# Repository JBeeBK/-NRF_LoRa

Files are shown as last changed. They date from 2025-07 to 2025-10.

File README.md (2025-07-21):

# NRF_LoRa

PCB design for a Nordic nRF52840 (QFN48) with SX1262 LoRa module.  
Designed as a low-power mesh node for experimentation and LoRaWan or Meshtastic development.

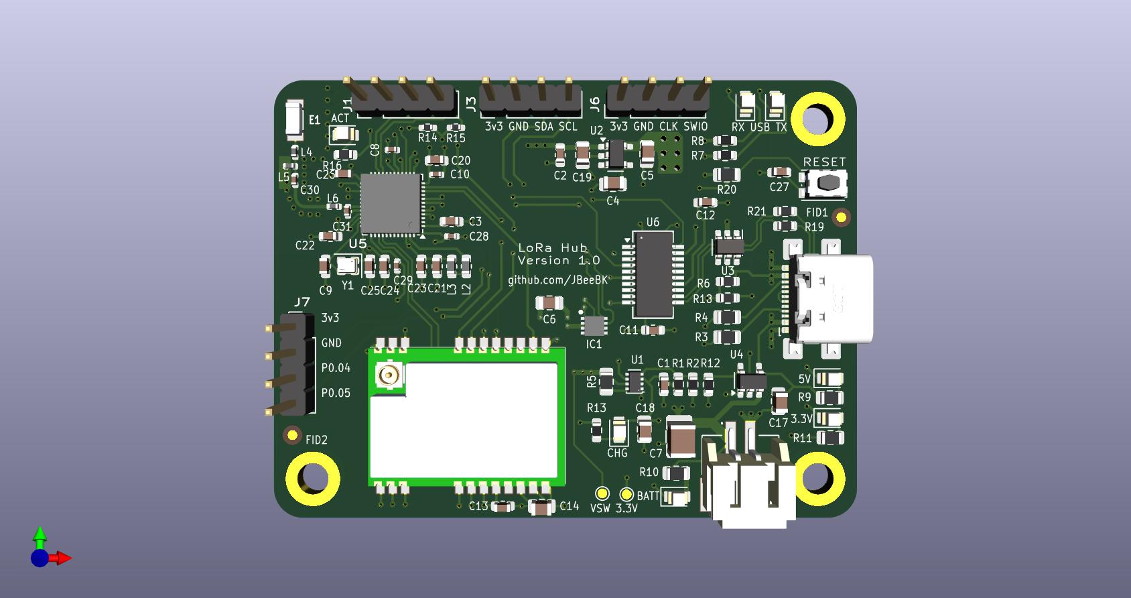
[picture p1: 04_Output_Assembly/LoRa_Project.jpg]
Board Top


### Features
- nRF52840 SoC (BLE, Cortex-M4F)
- SX1262 LoRa (868 MHz) with SMA antenna
- USB-C input with TPS2116 power multiplexer
- MCP73831 LiPo charger and MAX17048 fuel gauge
- 2 x I²C headers for OLED and maybe card keyboard
- FT231XS USB-UART bridge for programming
- Compact 4-layer PCB (60 x 45 mm)
- Additional Header for 2GPIO

### Repository Structure
- `Hardware/` – KiCad source files (schematic, PCB, symbols, footprints)
- `Documents/` – Excel for pinout and pins used, net labels, etc.
- `Output_Pcb/` – Gerbers, fabrication layer PDFs
- `Output_Assembly/` – BOM, pick-and-place, schematic PDFs
- `Firmware/` – C++ file

This repo documents the hardware design; firmware will be added once the board is fabricated.

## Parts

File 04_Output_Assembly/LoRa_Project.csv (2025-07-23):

Id | Designator | Footprint | Quantity | Designation | Supplier and ref
1 | C29,C10,C8,C28,C26 | C_0402_1005Metric | 5 | 100nF
2 | J3,J7,J6,J1 | PinHeader_1x04_P2.54mm_Vertical | 4 | Conn_01x04_Pin
3 | U4 | SOT-23-5 | 1 | MCP73831-2-OT
4 | D7 | LED_0805 | 1 | LED Green
5 | TP5 | TestPoint_Pad_D1.0mm | 1 | 3V3
6 | C12 | C_0603_1608Metric | 1 | 100nF
7 | C27,C11,C13,C3 | C_0603_1608Metric | 4 | 100nF
8 | C5,C14,C19 | C_0805_2012Metric | 3 | 1uF
9 | D6 | LED_0805 | 1 | LED Orange
10 | R15,R14 | R_0402_1005Metric_Pad0.72x0.64mm_HandSolder | 2 | 4k7
11 | TP4 | TestPoint_Pad_D1.0mm | 1 | V_SW
12 | D2 | LED_0805 | 1 | LED Blue
13 | U1 | SOT-583-8 | 1 | TPS2116DRLR
14 | C6,C18,C17 | C_0805_2012Metric | 3 | 100nF
15 | C21,C20 | C_0603_1608Metric | 2 | 1uF
16 | R10,R9 | R_0805_2012Metric | 2 | 1K5_0805
17 | R5,R20 | R_0805_2012Metric | 2 | 10K
18 | R13 | R_0603_1608Metric | 1 | 1K
19 | Y1 | Crystal_SMD_2016-4Pin_2.0x1.6mm | 1 | Crystal
20 | C1,C2 | C_0603_1608Metric | 2 | 10uF
21 | R2,R1 | R_0603_1608Metric | 2 | 100K
22 | U3 | SOT-23-6 | 1 | USBLC6-2SC6
23 | IC2 | E22-900M22S | 1 | E22-900M22S
24 | R16 | R_0603_1608Metric | 1 | 1K_0603
25 | L6 | L_0402_1005Metric | 1 | 4.7nH
26 | R11 | R_0805_2012Metric | 1 | 1K_0805
27 | U2 | SOT-23-5 | 1 | MIC5219-3.3YM5
28 | U6 | SSOP-20_3.9x8.7mm_P0.635mm | 1 | FT231XS
29 | D3 | LED_0805 | 1 | USB PWR
30 | R12 | R_0603_1608Metric | 1 | 10K0_0603
31 | IC1 | SON50P200X200X80-9N-D | 1 | MAX17048G+T10
32 | U5 | QFN-48-1EP_6x6mm_P0.4mm_EP4.6x4.6mm_ThermalVias | 1 | nRF52840-QFAA
33 | J2 | USB_C_Receptacle_GCT_USB4110 | 1 | USB_C_Receptacle_USB2.0_16P
34 | R8,R7 | R_0603_1608Metric | 2 | 270R_0603
35 | R18 | R_0603_1608Metric | 1 | 10K
36 | L5 | L_0402_1005Metric | 1 | 2.7nH
37 | C24 | C_0603_1608Metric | 1 | 100pF
38 | C31 | C_0402_1005Metric | 1 | 1pF
39 | R3,R4 | R_0805_2012Metric | 2 | 5K1_0805
40 | L3 | L_0603_1608Metric | 1 | 15uH
41 | C25,C9 | C_0603_1608Metric | 2 | 8pF
42 | C23 | C_0603_1608Metric | 1 | C_NP
43 | L2 | L_0603_1608Metric | 1 | 10uH
44 | D5 | LED_0805 | 1 | VREG
45 | L4 | L_0402_1005Metric | 1 | 3.3nH
46 | C22 | C_0603_1608Metric | 1 | 47nF
47 | C7 | C_1210_3225Metric | 1 | 10uF
48 | RST1 | SW_Push_1P1T_NO_CK_KMR2 | 1 | ~
49 | R19,R21 | R_0603_1608Metric | 2 | 27
50 | D4 | LED_0805 | 1 | BATT PWR
51 | C4 | C_0805_2012Metric | 1 | 470pF
52 | C30 | C_0402_1005Metric | 1 | 1.2pF
53 | J4 | JST_S2B-PH-SM4-TB_LF__SN_ | 1 | Header_01x02_2.0mm JST PH
54 | E1 | XDCR_2450AT18B100E | 1 | 2450AT18B100E
55 | D1 | LED_0805 | 1 | LED Yellow
56 | R6 | R_0603_1608Metric | 1 | 4k7

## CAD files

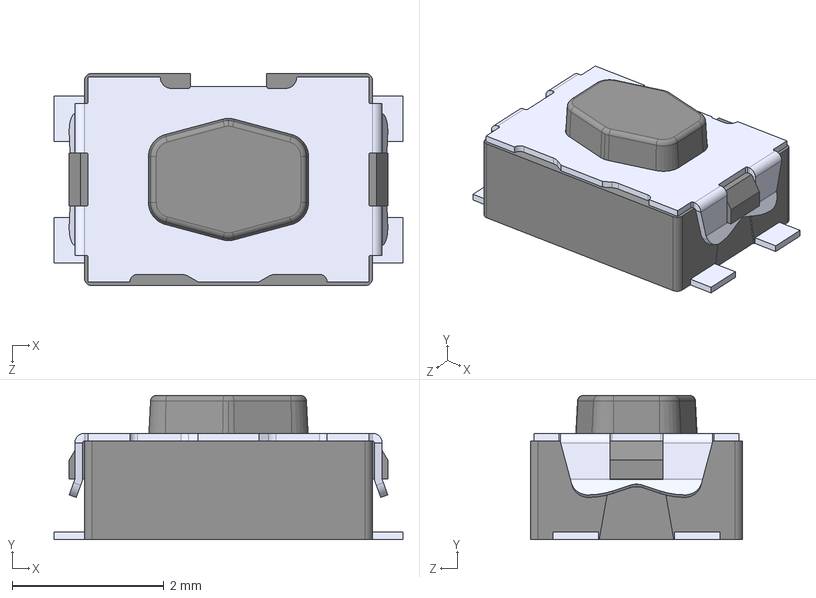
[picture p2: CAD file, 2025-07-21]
00_Hardware/Project_Footprints/KMR211NGLFS.STEP
4.60 x 1.90 x 2.80 mm

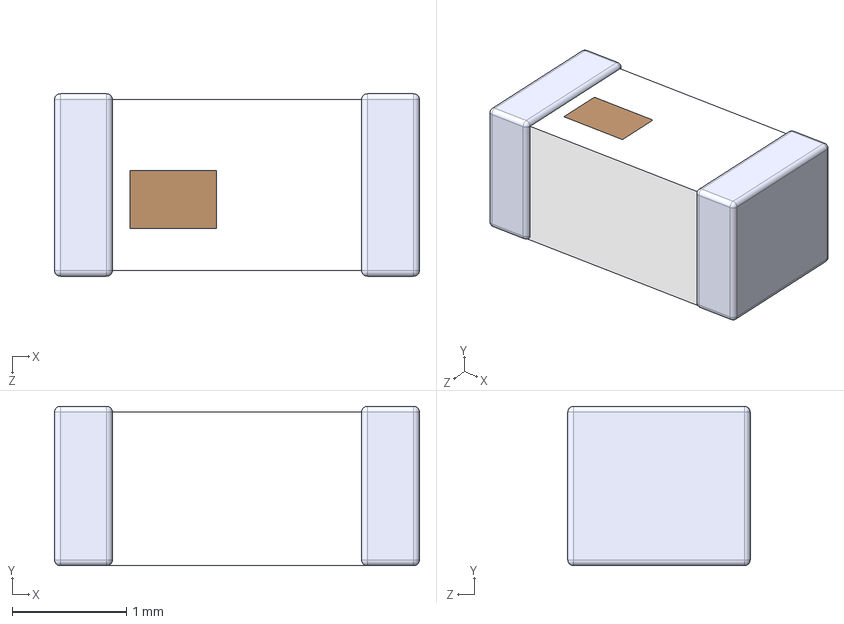
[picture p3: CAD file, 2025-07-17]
00_Hardware/Project_Footprints/2450AT18B100E.step
3.20 x 1.40 x 1.60 mm

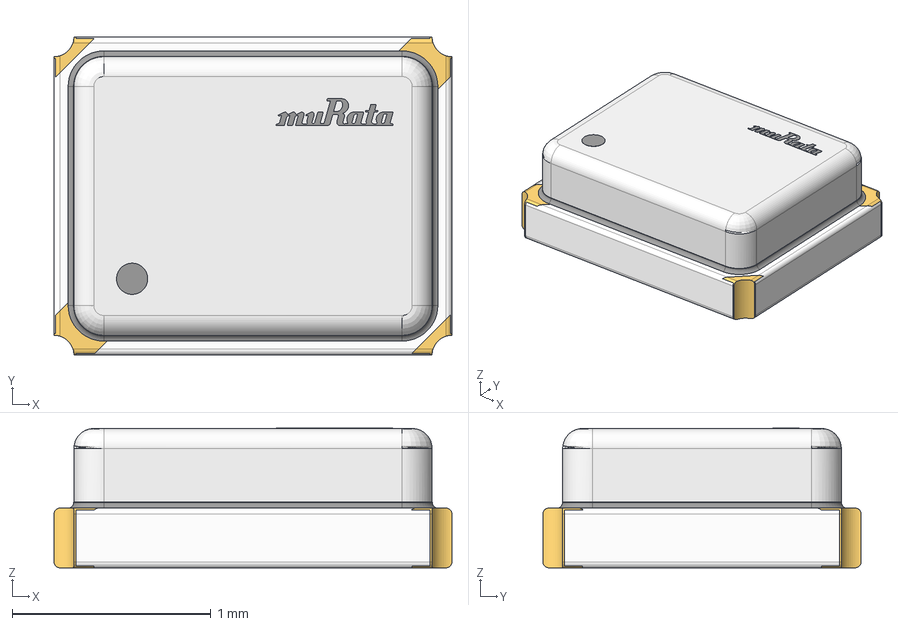
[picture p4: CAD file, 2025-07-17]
00_Hardware/Project_Footprints/XRCGB32M000F1SBJR0-.STEP
2.00 x 1.60 x 0.702 mm

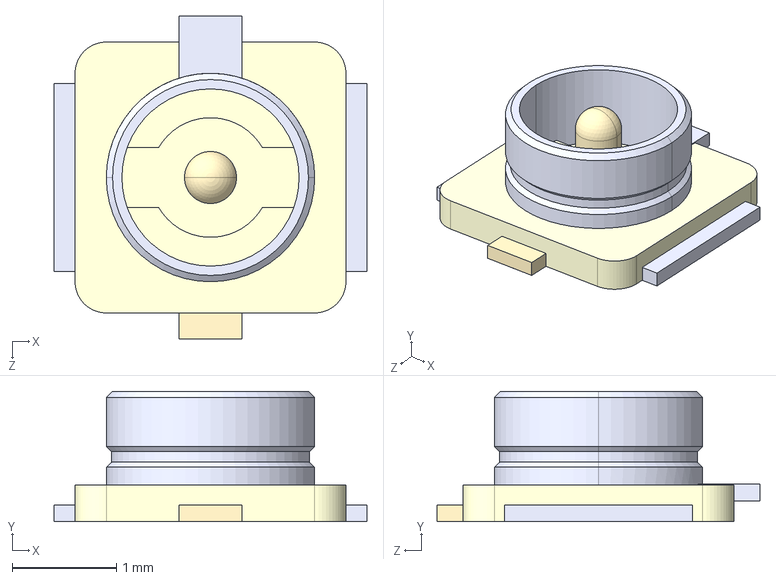
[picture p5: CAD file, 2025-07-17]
00_Hardware/Project_Footprints/U.FL-R-SMT_01_.step
3.00 x 1.25 x 3.10 mm

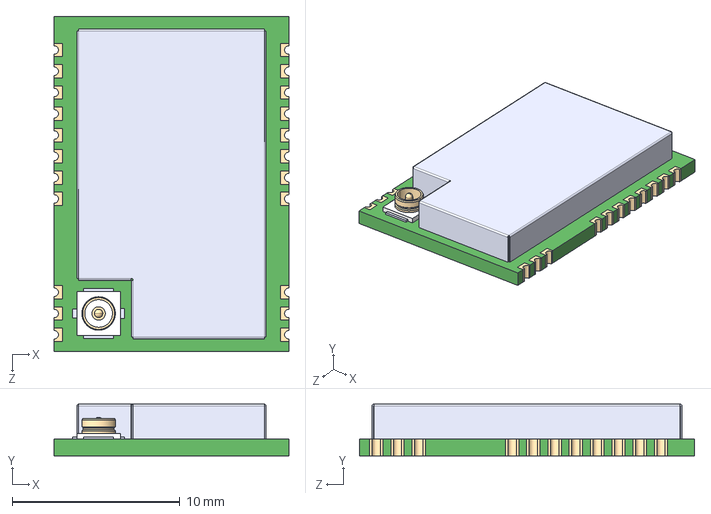
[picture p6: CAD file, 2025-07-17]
00_Hardware/Project_Footprints/E22-900M22S.step
14.0 x 3.10 x 20.0 mm

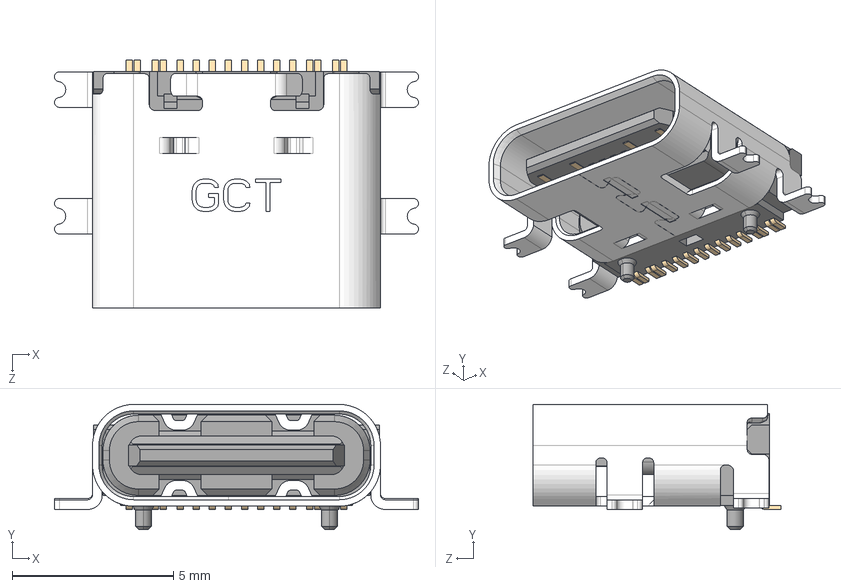
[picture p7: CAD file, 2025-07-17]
00_Hardware/Project_Footprints/USB4110-GF-A.stp
11.3 x 3.89 x 7.70 mm

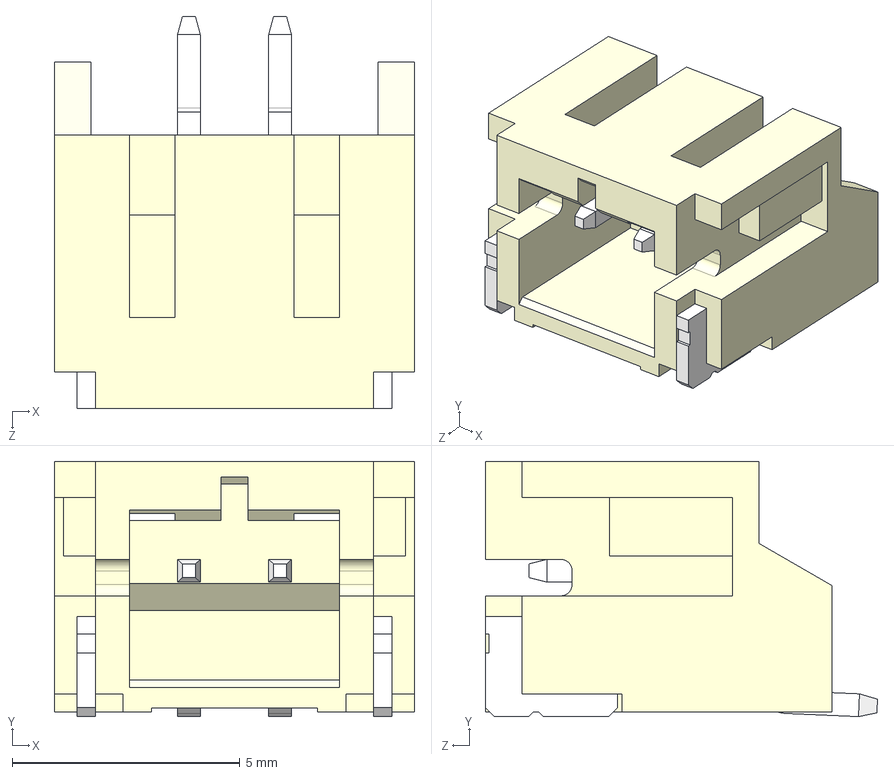
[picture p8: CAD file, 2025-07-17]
00_Hardware/Project_Footprints/S2B-PH-SM4-TB_LF__SN_.step
7.90 x 5.60 x 8.60 mm

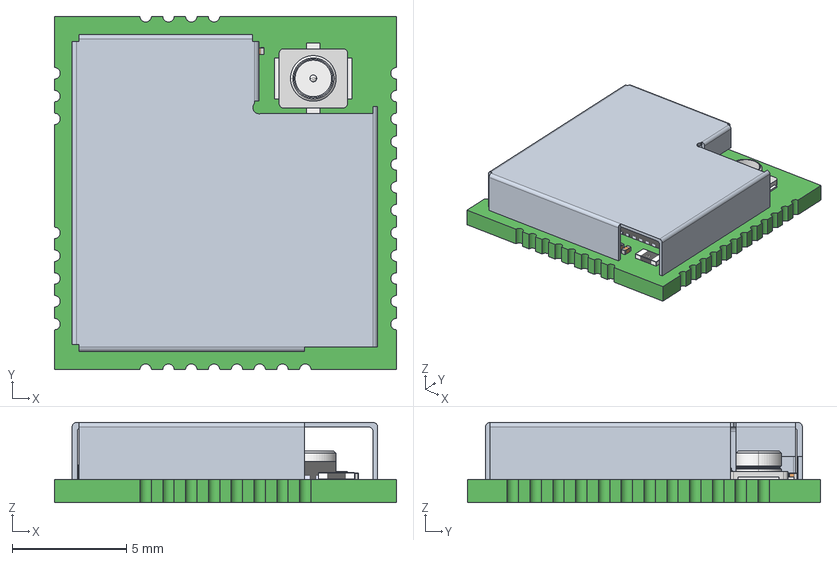
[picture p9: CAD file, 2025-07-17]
00_Hardware/Project_Footprints/RAK3172.step
15.0 x 15.5 x 3.51 mm
0201_SMD_Capacitor x 36
Extruded
R0201 x 7
RES_1005-0402 x 3
QFN48_7x7
NT2016SA
C0402 x 4
crystal_rtf2012
D030A-そ敖裔

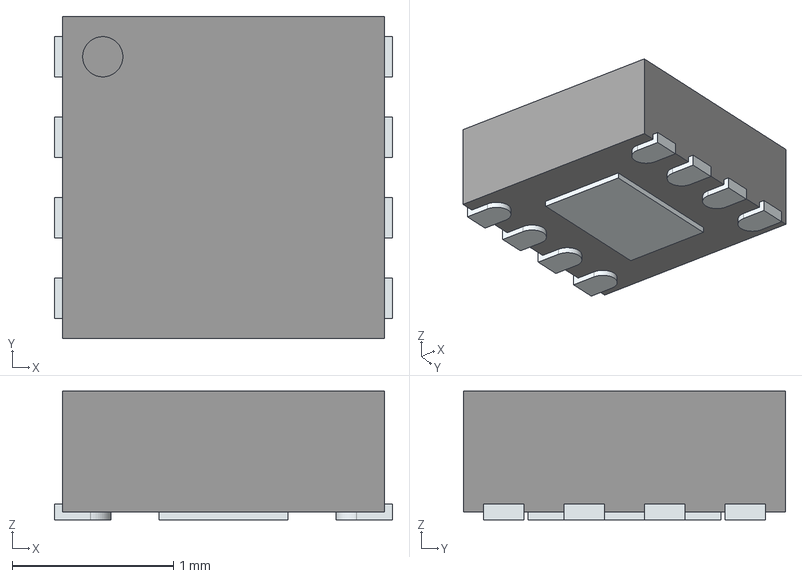
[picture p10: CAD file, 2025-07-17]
00_Hardware/Project_Footprints/MAX17048G+T10.stp
2.10 x 2.00 x 0.8 mm
ThermalPin
PinsArrayLR

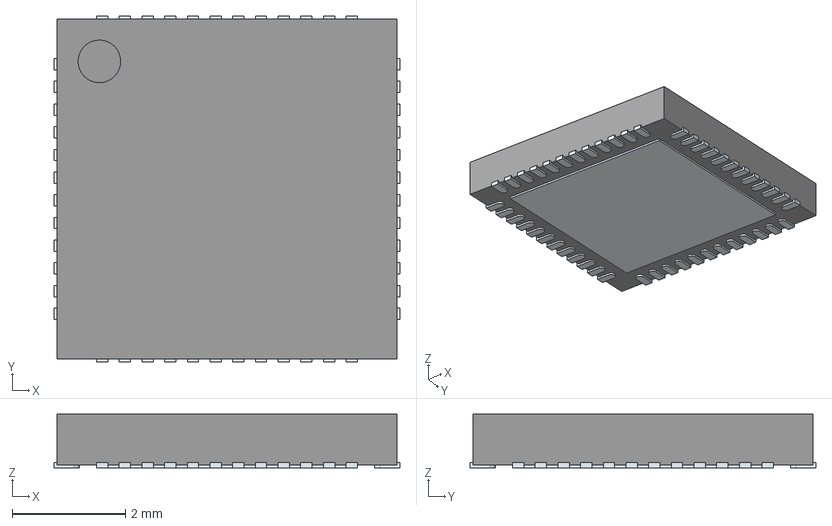
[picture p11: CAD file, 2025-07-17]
00_Hardware/Project_Footprints/nRF52840-QFAA-F-R7.stp
6.10 x 6.10 x 0.95 mm
ThermalPin
PinsArrayLR
PinsArrayTB

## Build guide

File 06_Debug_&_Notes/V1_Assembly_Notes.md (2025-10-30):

# Version 1.0 Bring-Up Notes

## Overview
First assembled prototype of the nRF52840 + SX1262 board.  

First run was a huge PITA to hand solder. I did the MCU and a few others with the oven and that went well, but the 0402s had not arrived yet and those took a bit of time. 
Not using BATT yet until firmware is running.

## Issues Found
### 1. USB ESD Protection (USBLC6-2SC6)
- **Problem:** D+ and D− were shorted because pins 1↔6 and 3↔4 were tied together incorrectly.
- **Fix:** Removed the ESD IC and jumpered D+ and D− directly through to the FTDI. Board enumerates correctly as a COM port after rework.

### 2. Bpost bent the stencil in the mail

### 3. I should have waited until I had all the components and just done one pass in the oven.

## Photos
| Description | Image |
|---|---|
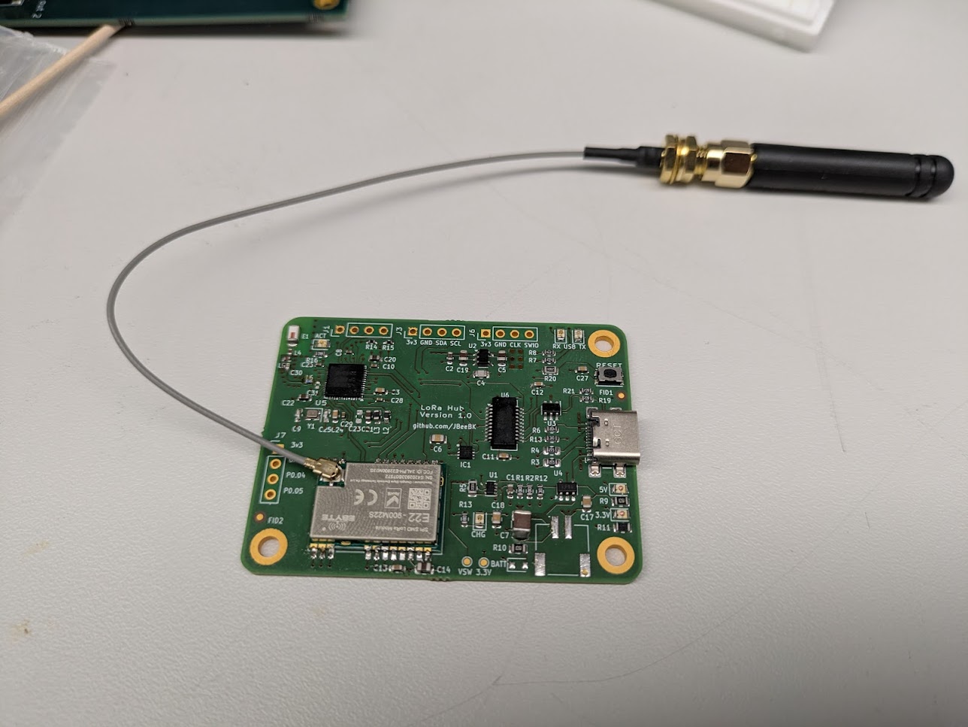
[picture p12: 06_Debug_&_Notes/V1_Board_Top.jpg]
Top side
| Hand-soldered top side |  |
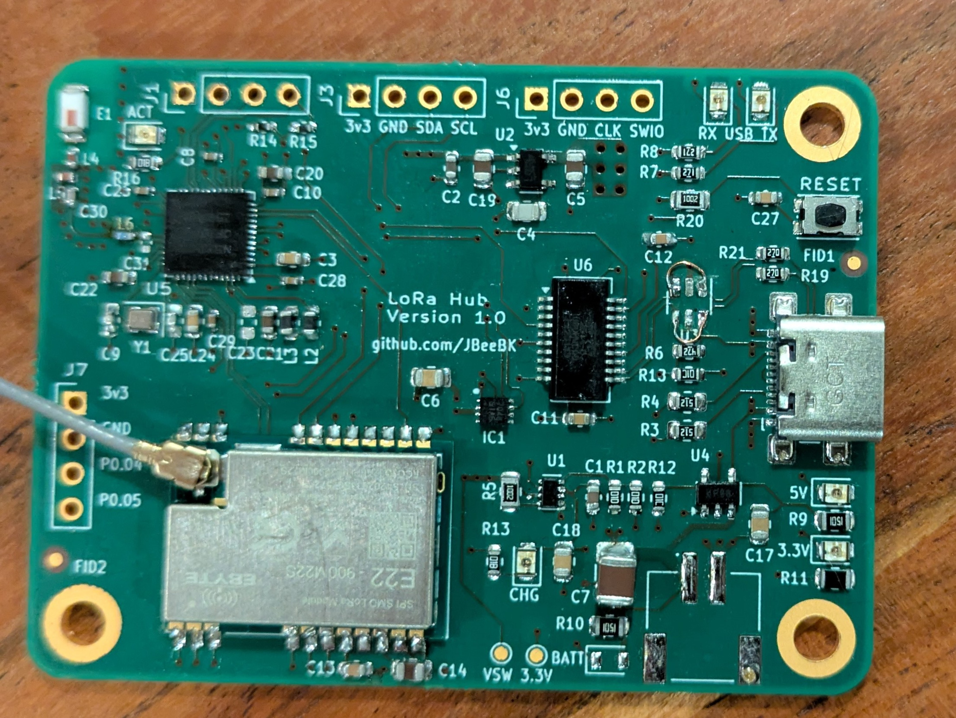
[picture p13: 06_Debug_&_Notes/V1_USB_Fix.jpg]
USB fix
| ESD rework on USB lines |  |

## Next Steps
- Validate UART communication to nRF52840. Had to order some DAPlink converter because I have nothing like this.
- Verify SWD programming access.
- Begin firmware bring-up (blink test + UART loopback).

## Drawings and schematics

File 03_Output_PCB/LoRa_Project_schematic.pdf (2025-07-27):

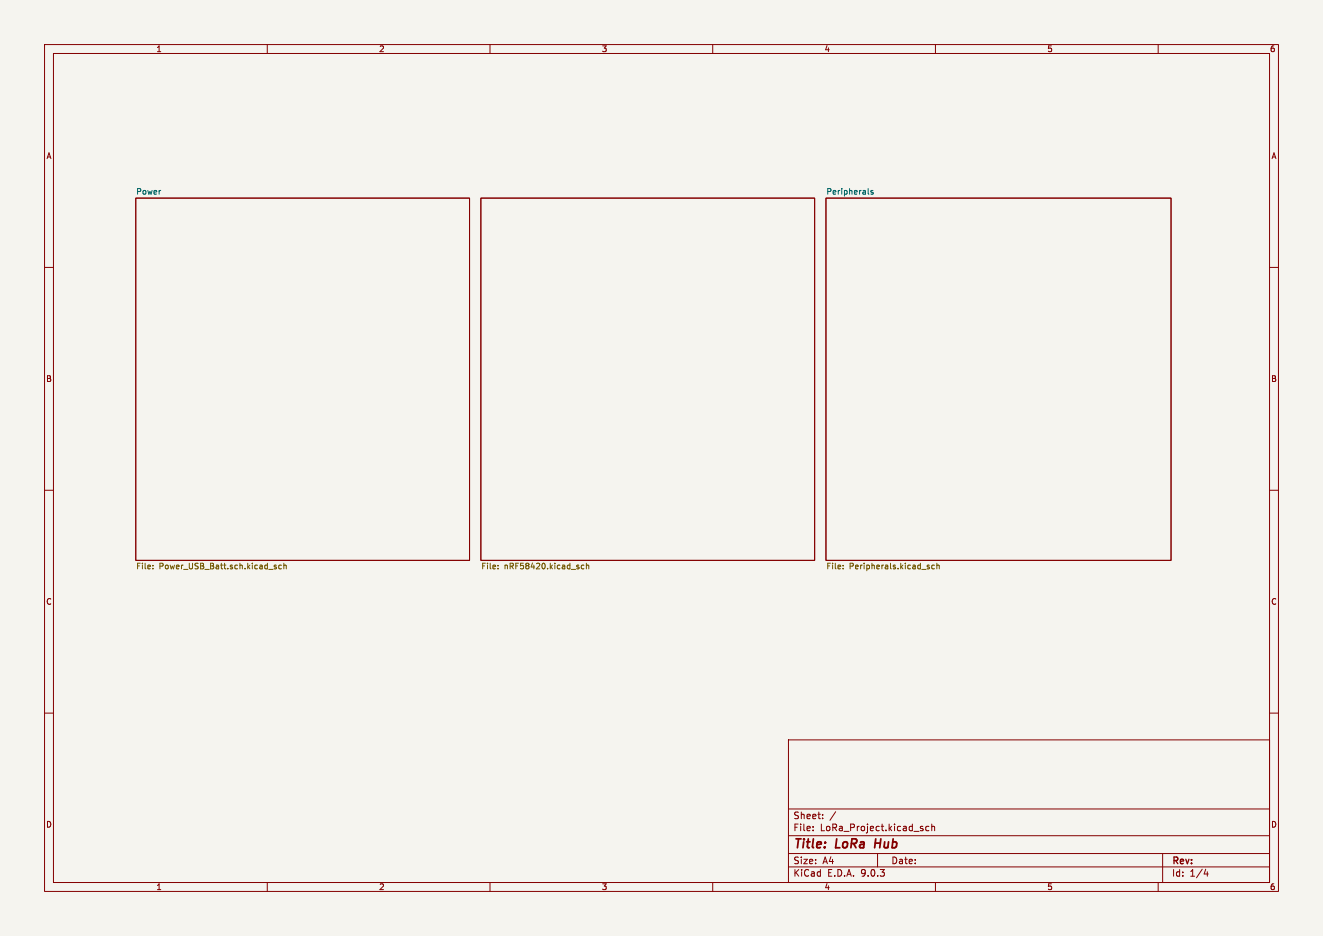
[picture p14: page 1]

Id: 1/4 Title: LoRa Hub

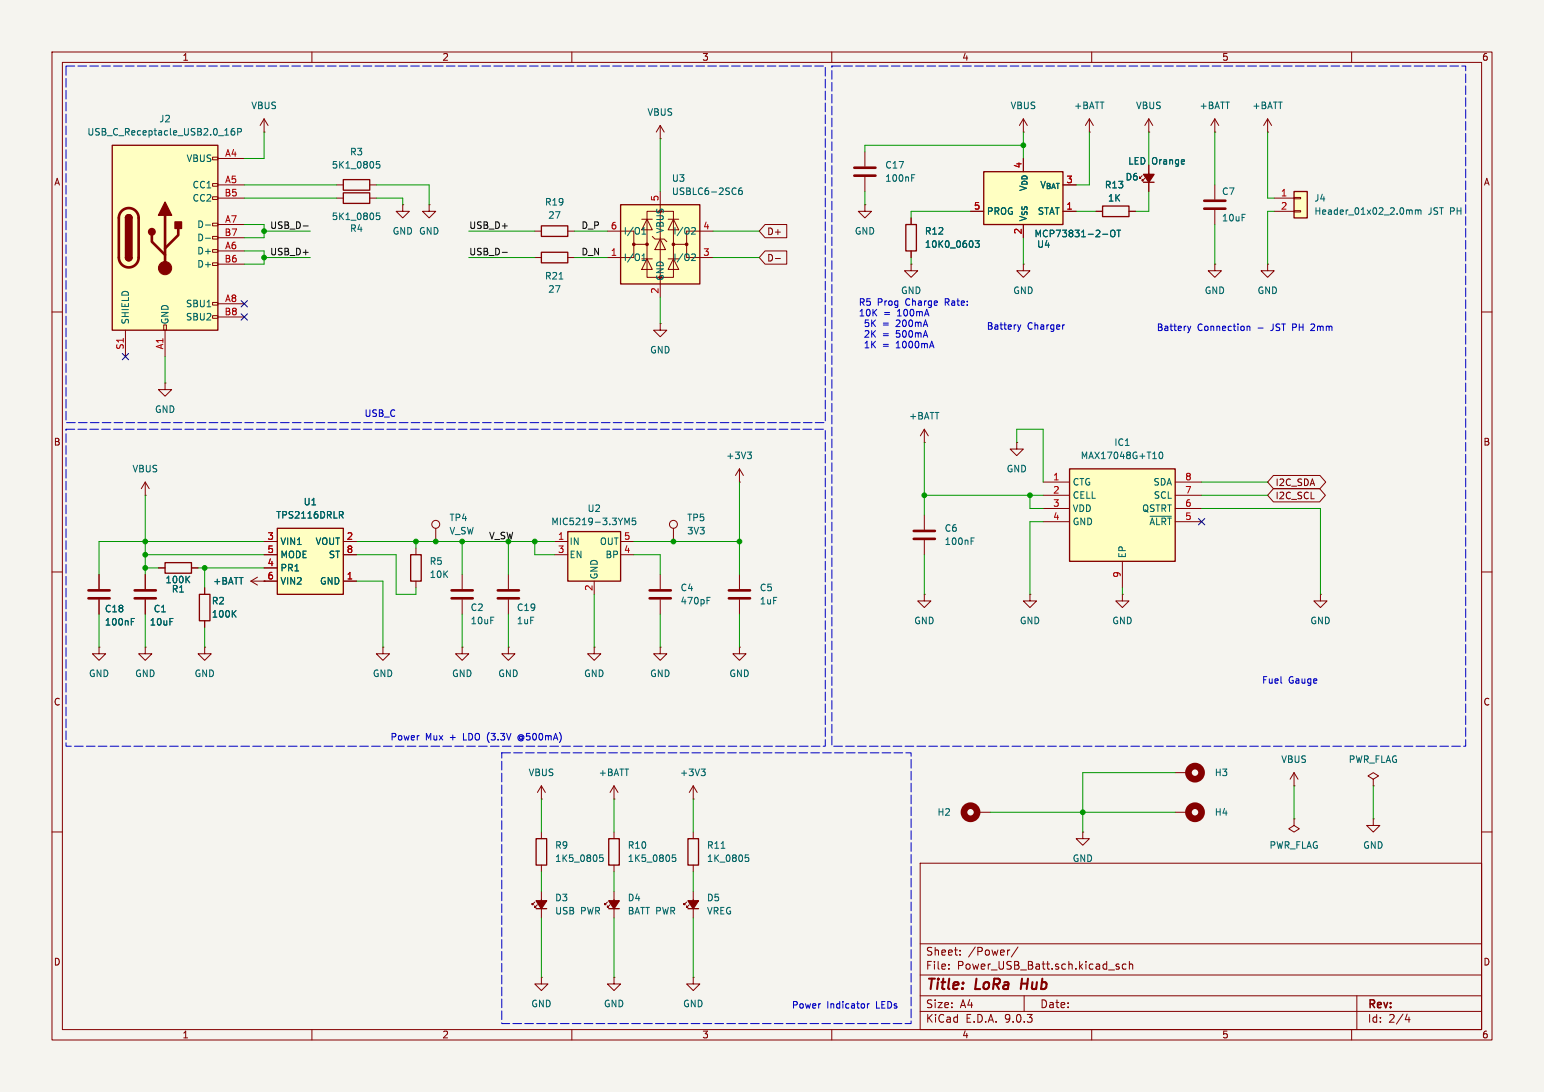
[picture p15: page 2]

9 SDA 8 SCL 7 QSTRT 6 ~{ALRT}5

File: Power_USB_Batt.sch.kicad_sch Sheet: /Power/ GND

Id: 2/4 Title: LoRa Hub

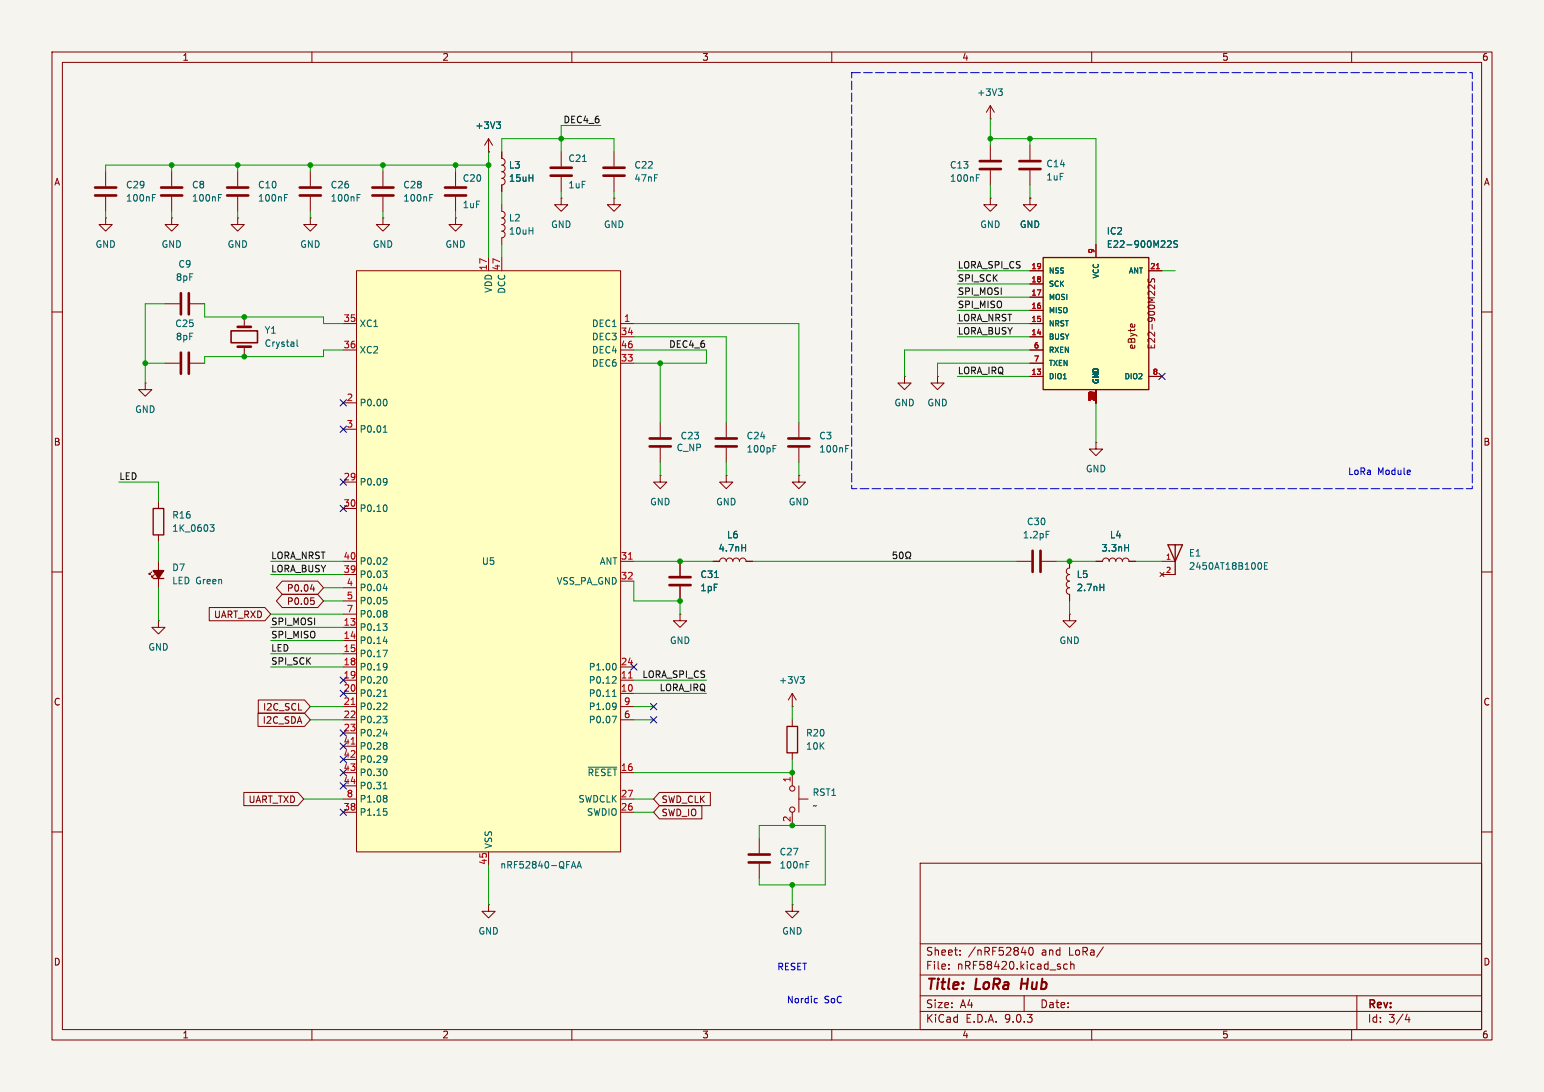
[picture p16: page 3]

LoRa Module Nordic SoC

Id: 3/4 Title: LoRa Hub

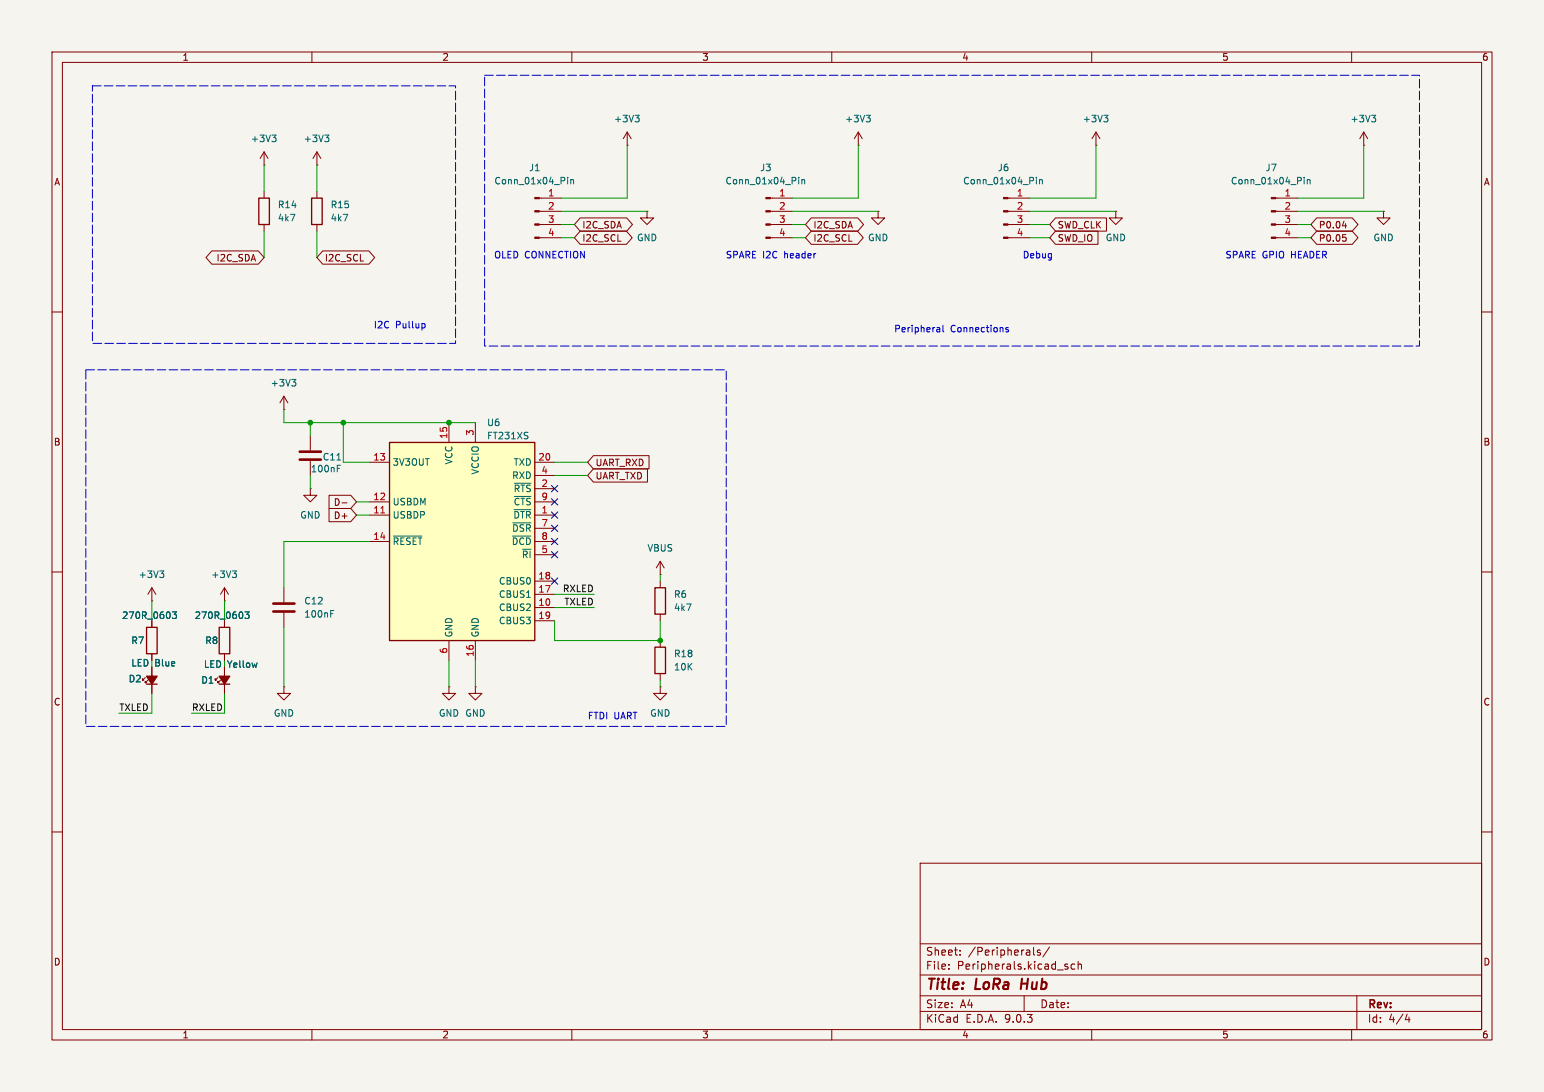
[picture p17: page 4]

3 GND 16 TXD 20 RXD 4 ~{RTS}2 ~{CTS}9 ~{DTR}1 ~{DSR}7 ~{DCD}8 ~{RI}5 CBUS0 18 CBUS1 17 CBUS2 10 CBUS3 19 U6 FT231XS R7

File: Peripherals.kicad_sch Sheet: /Peripherals/
Id: 4/4 Title: LoRa Hub

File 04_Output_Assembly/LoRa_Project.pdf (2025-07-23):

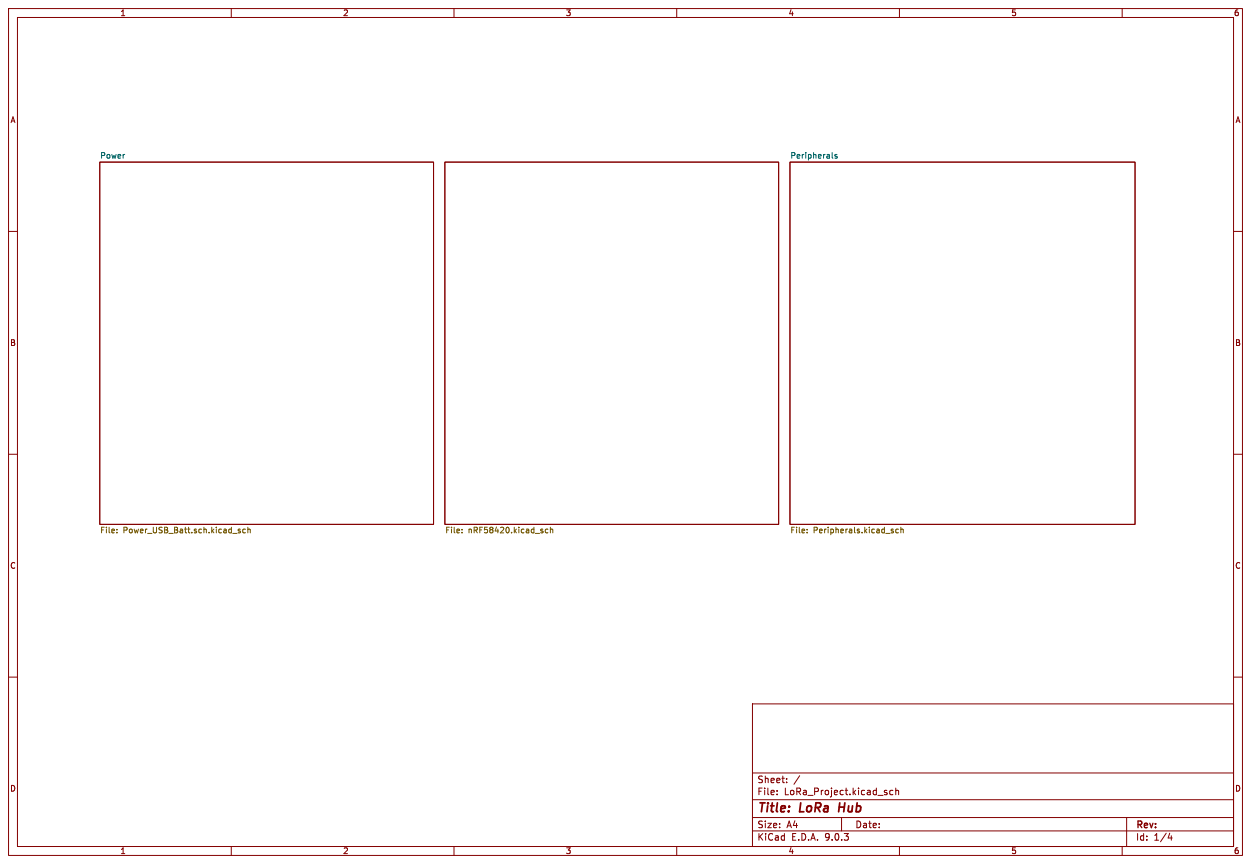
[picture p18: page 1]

Id: 1/4 Title: LoRa Hub

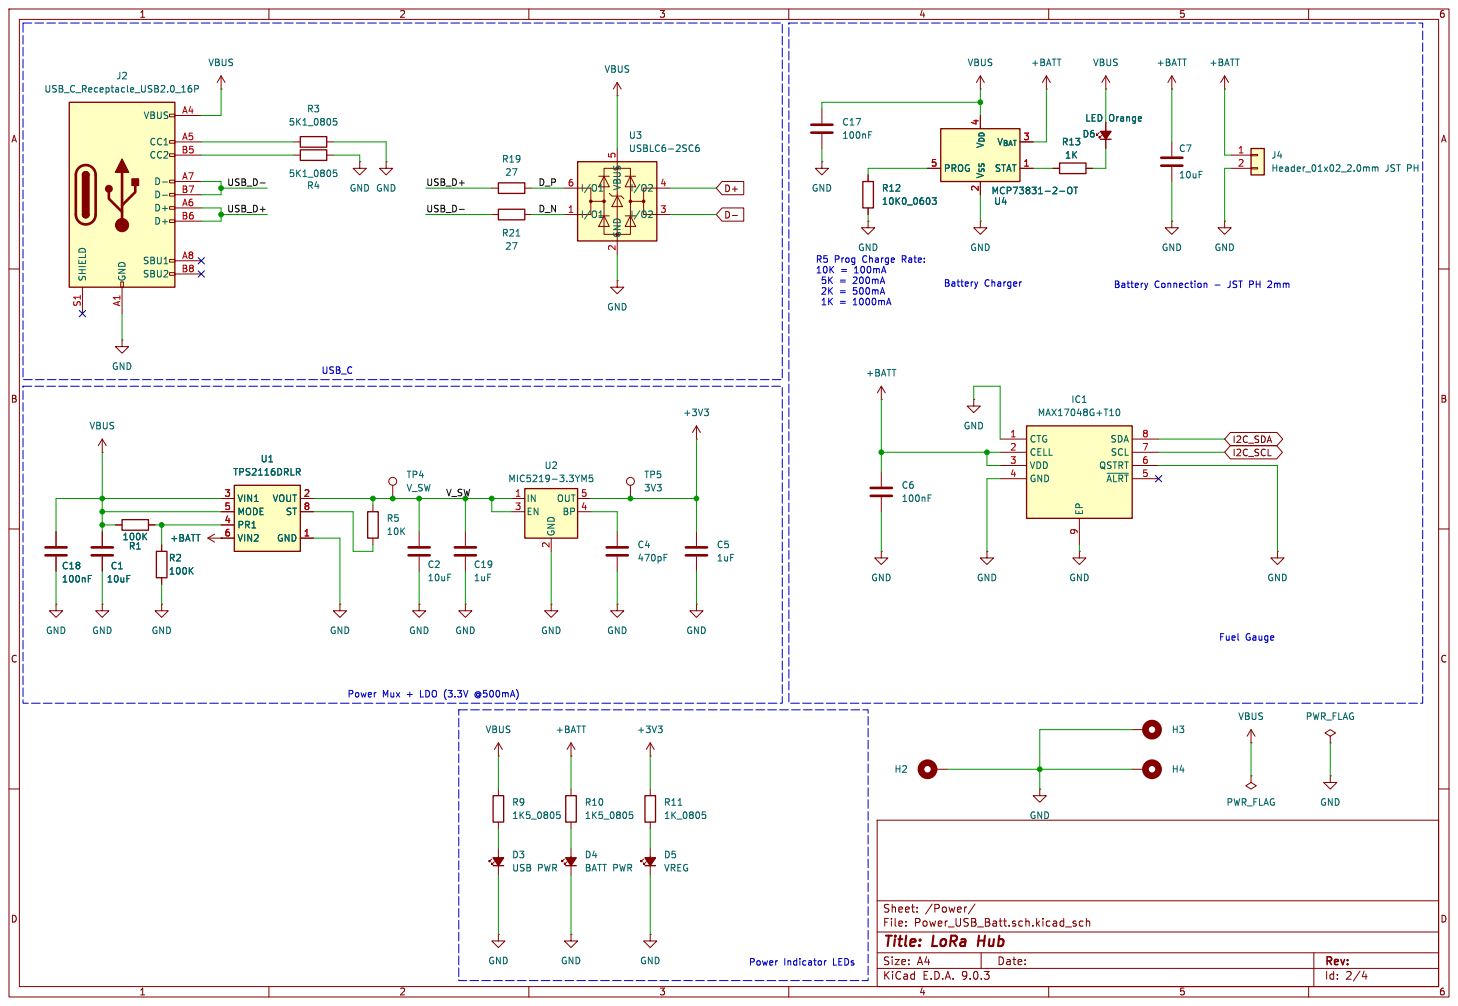
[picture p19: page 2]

9 SDA 8 SCL 7 QSTRT 6 ~{ALRT}5

File: Power_USB_Batt.sch.kicad_sch Sheet: /Power/ R1

Id: 2/4 Title: LoRa Hub

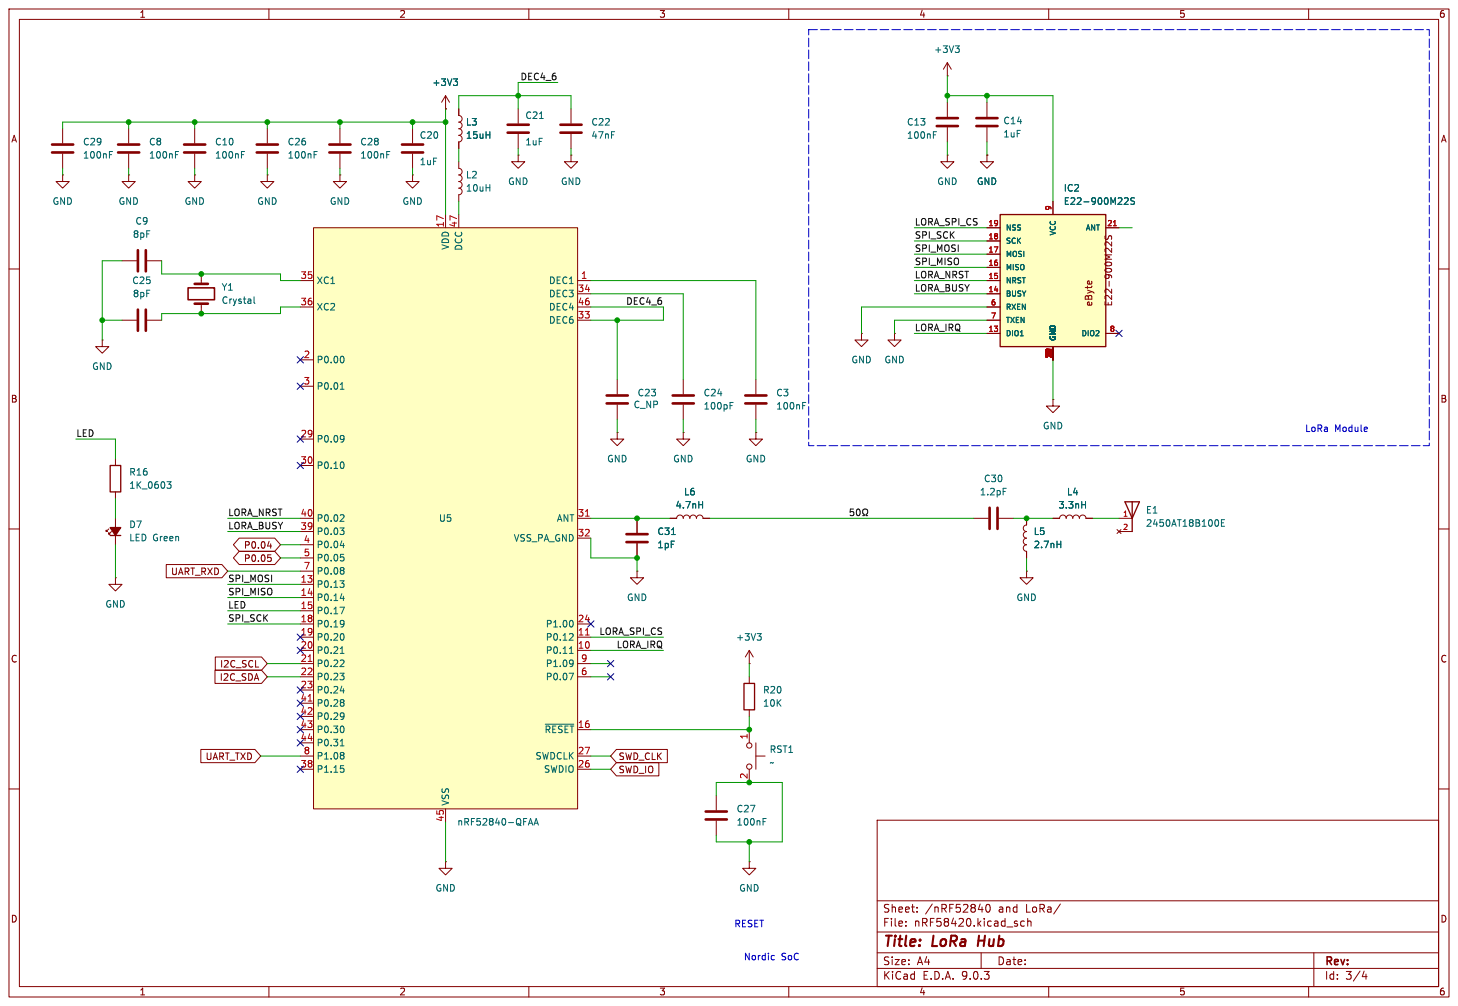
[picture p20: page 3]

LoRa Module Nordic SoC

Id: 3/4 Title: LoRa Hub

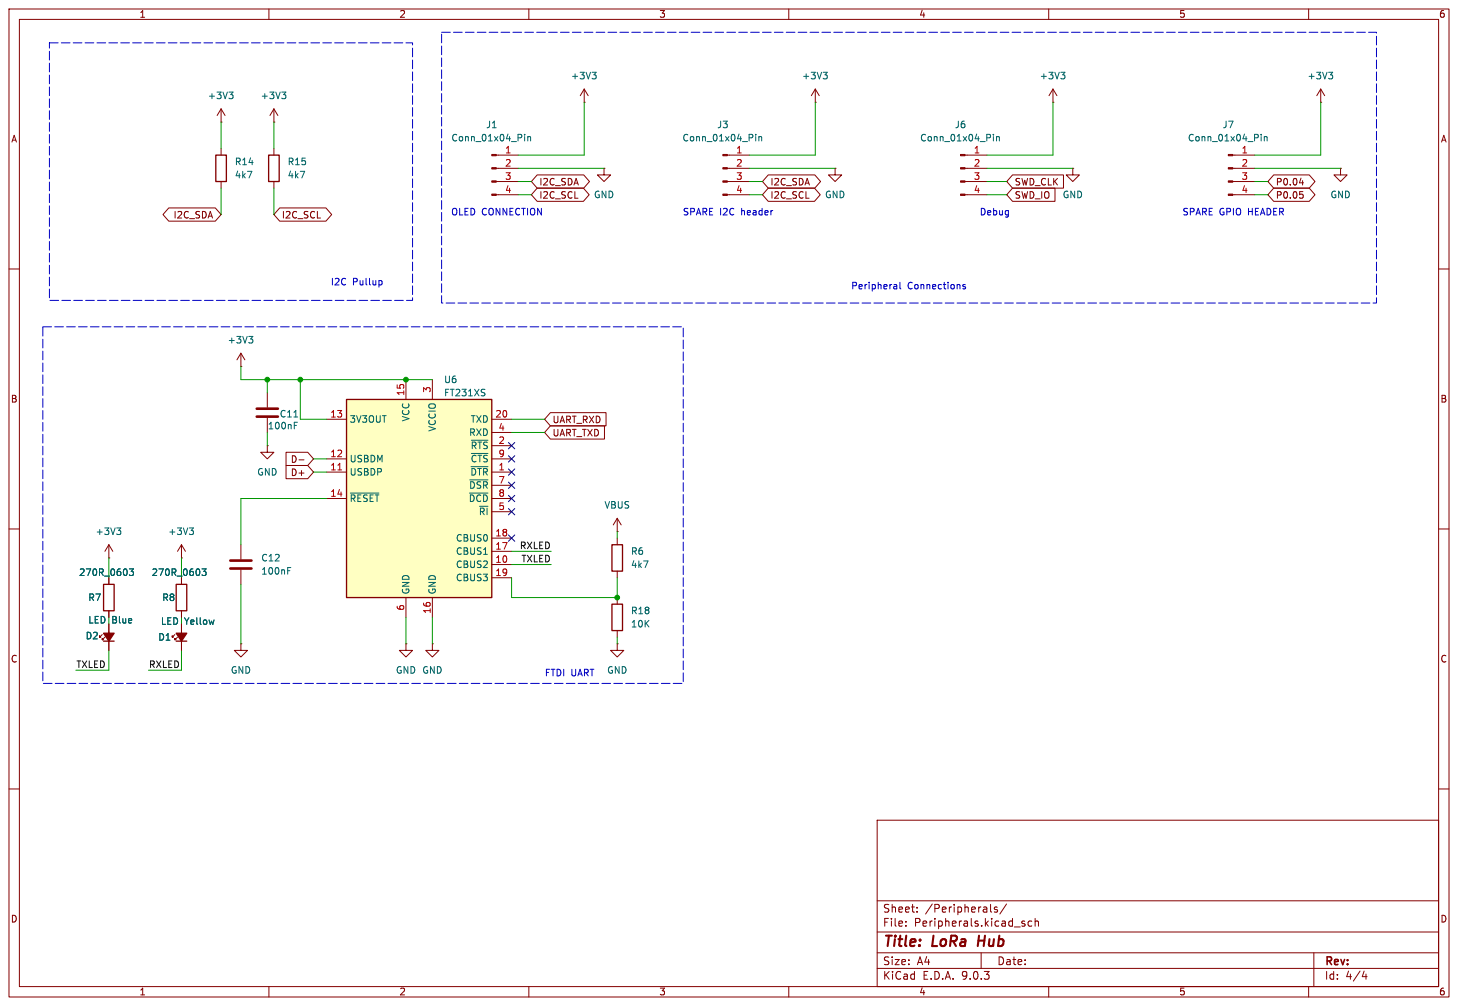
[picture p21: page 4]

3 GND 16 TXD 20 RXD 4 ~{RTS}2 ~{CTS}9 ~{DTR}1 ~{DSR}7 ~{DCD}8 ~{RI}5 CBUS0 18 CBUS1 17 CBUS2 10 CBUS3 19 U6 FT231XS R14

File: Peripherals.kicad_sch Sheet: /Peripherals/
Id: 4/4 Title: LoRa Hub

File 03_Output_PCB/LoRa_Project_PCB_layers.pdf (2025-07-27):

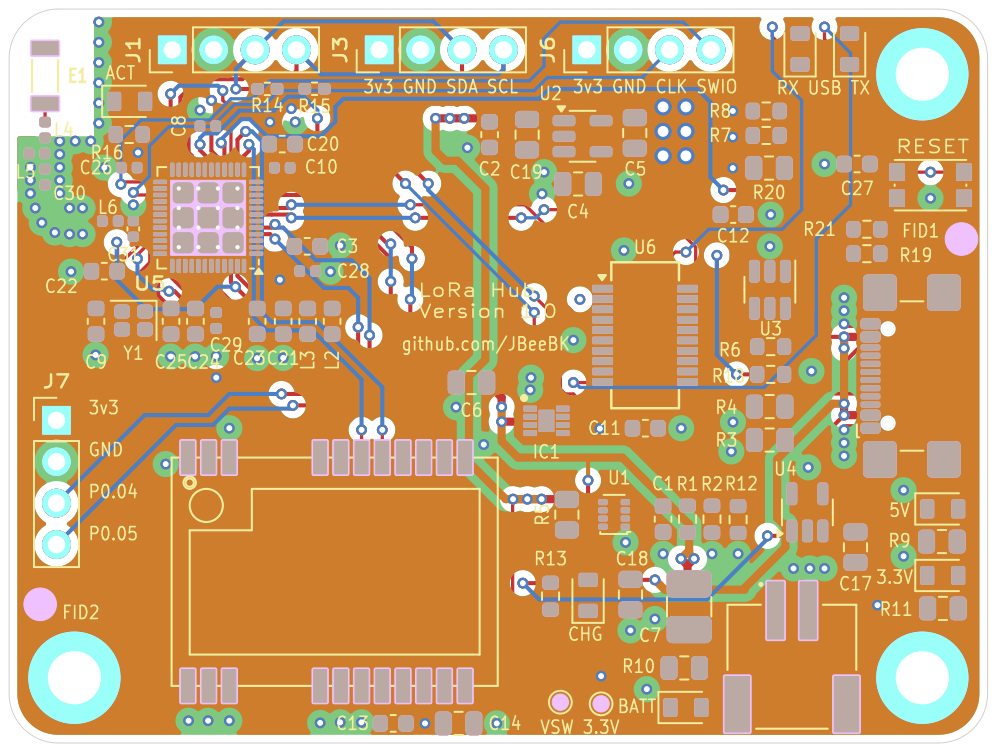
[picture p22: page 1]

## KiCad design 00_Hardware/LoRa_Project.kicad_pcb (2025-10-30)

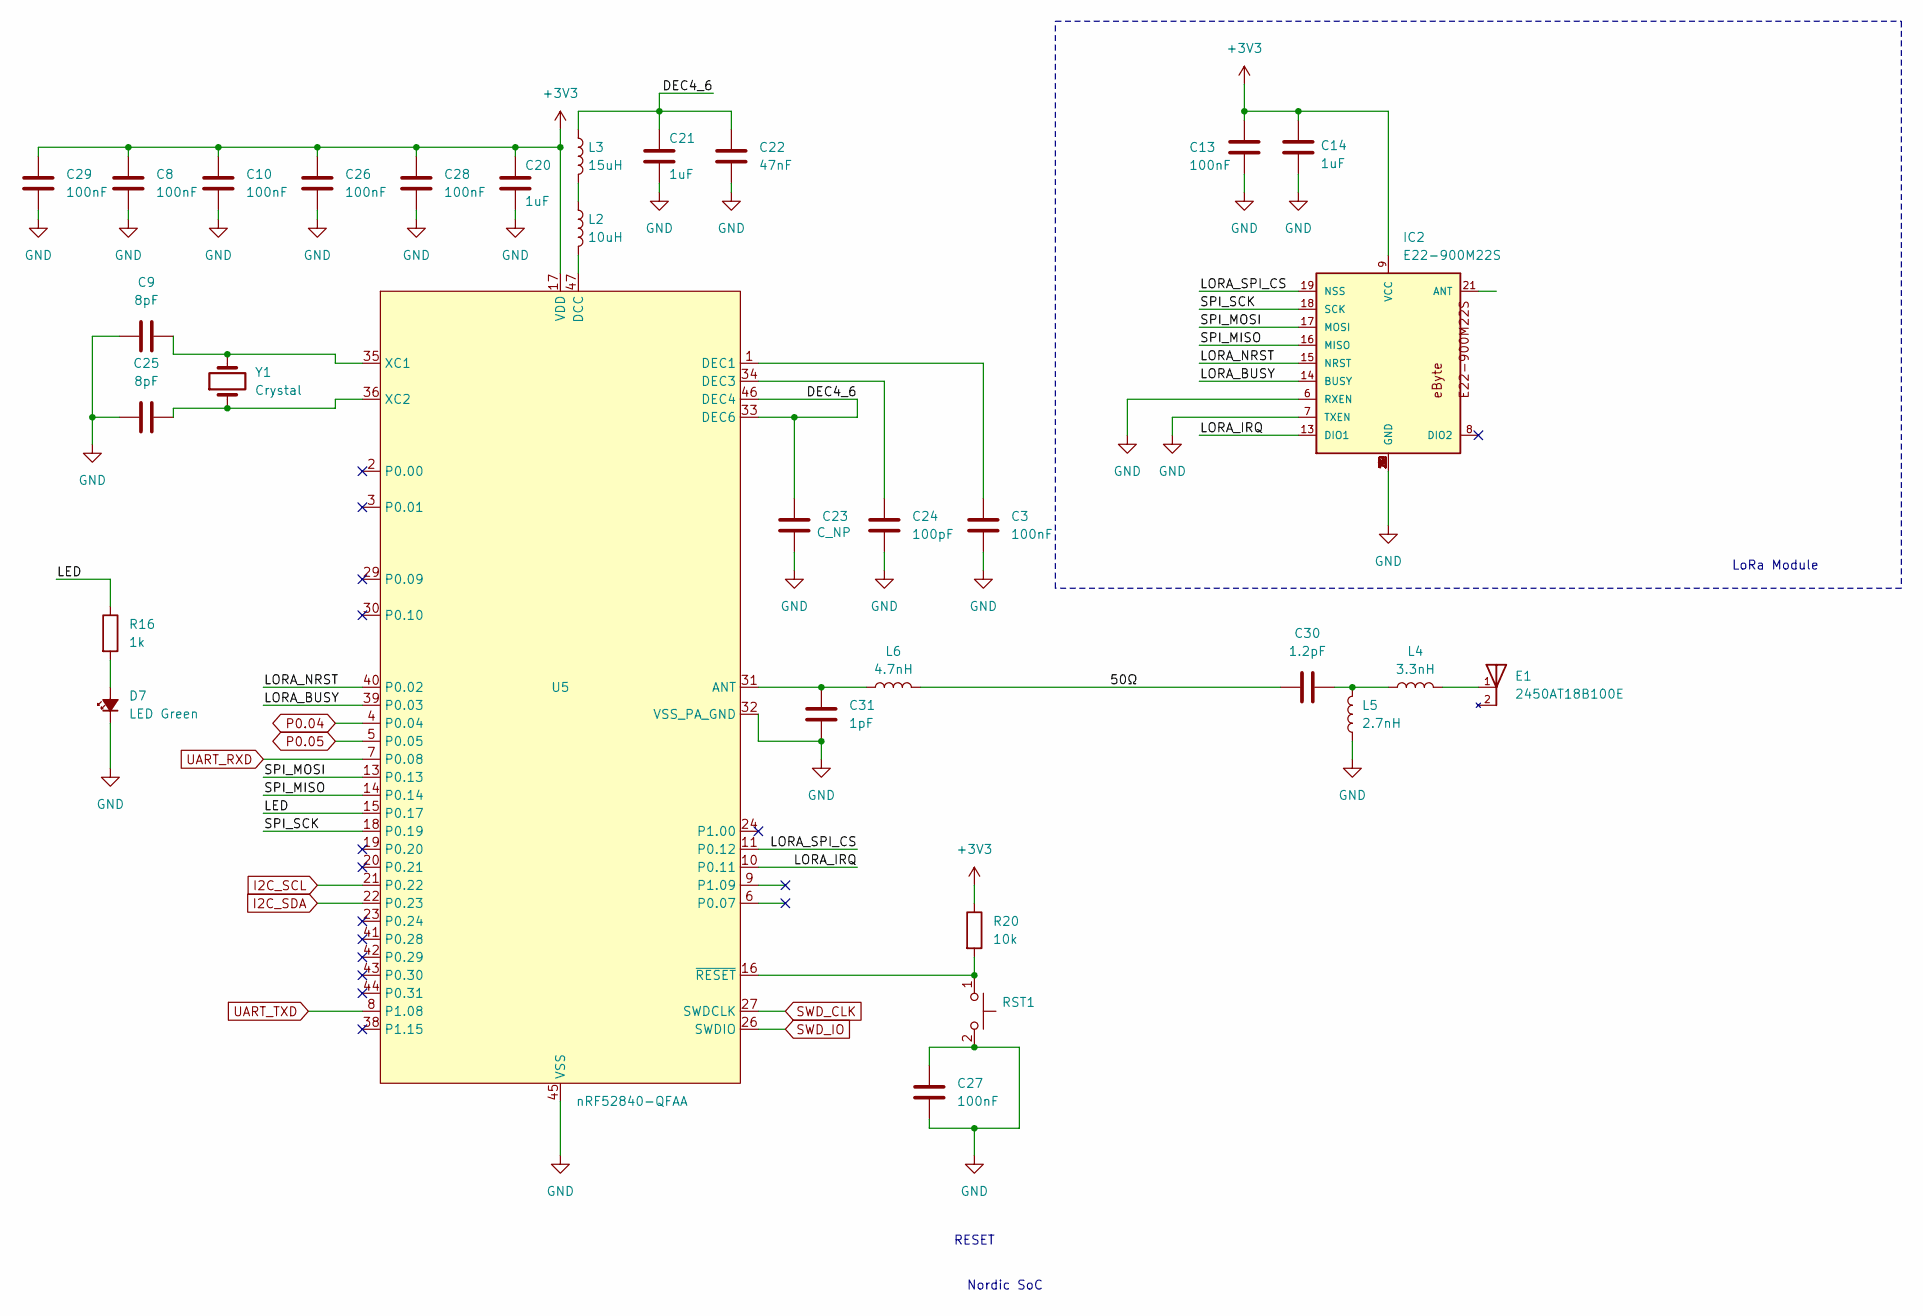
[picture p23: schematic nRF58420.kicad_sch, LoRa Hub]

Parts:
C3: 100nF; C_0603_1608Metric; MPN1 06033D104KAT2A; LCSC C14663
C8, C10, C26, C28, C29: 100nF; C_0402_1005Metric; MPN1 0402YC104KAT2A
C9, C25: 8pF; C_0603_1608Metric; MPN1 06033A8R0DAT2A
C13, C27: 100nF; C_0603_1608Metric; MPN1 06033D104KAT2A
C14: 1uF; C_0805_2012Metric; MPN1 08053C105KAT2A
C20, C21: 1uF; C_0603_1608Metric; MPN1 C0603C105K3RACTU
C22: 47nF; C_0603_1608Metric; MPN1 C0603X473J3RAC3316
C23: C_NP; C_0603_1608Metric; MPN1 ---
C24: 100pF; C_0603_1608Metric; MPN1 06033C101JAT4A
C30: 1.2pF; C_0402_1005Metric; MPN1 500R07S1R2BV4T
C31: 1pF; C_0402_1005Metric
D7: LED Green; LED_0805; MPN1 APTD2012LCGCK
E1: 2450AT18B100E; XDCR_2450AT18B100E; MPN1 2450AT18B100E
IC2: E22-900M22S; MPN1 E22-900M22S
L2: 10uH; L_0603_1608Metric; MPN1 LQW18AS10NG0ZD
L3: 15uH; L_0603_1608Metric; MPN1 LQW18AS10NG0ZD
L4: 3.3nH; L_0402_1005Metric; MPN1 L-07C3N3SV6T
L5: 2.7nH; L_0402_1005Metric; MPN1 L-07C2N7SV6T
L6: 4.7nH; L_0402_1005Metric
R16: 1k; R_0603_1608Metric
R20: 10k; R_0805_2012Metric; MPN1 CRCW080510K0FKEA
RST1: SW_Push_1P1T_NO_CK_KMR2; MPN1 KMR211NGLFS
U5: nRF52840-QFAA; QFN-48-1EP_6x6mm_P0.4mm_EP4.6x4.6mm_ThermalVias; MPN1 nRF52840-QFN
Y1: Crystal; Crystal_SMD_2016-4Pin_2.0x1.6mm; MPN1 XRCGB32M000F1SBJR0

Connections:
+3V3: C8.1, C10.1, C13.1, C14.1, C20.1, C26.1, C28.1, C29.1, IC2.9 (VCC), R20.1, U5.12 (VDD), U5.17 (VDD), U5.25 (VDD), U5.37 (VDD), U5.48 (VDD); also elsewhere on the board
/nRF52840 and LoRa/50Ω: C30.1, L6.2
/nRF52840 and LoRa/DEC4_6: C21.1, C22.1, C23.1, L3.1, U5.33 (DEC6), U5.46 (DEC4)
/nRF52840 and LoRa/LED: R16.1, U5.15 (P0.17)
/nRF52840 and LoRa/LORA_BUSY: IC2.14 (BUSY), U5.39 (P0.03)
/nRF52840 and LoRa/LORA_IRQ: IC2.13 (DIO1), U5.10 (P0.11)
/nRF52840 and LoRa/LORA_NRST: IC2.15 (NRST), U5.40 (P0.02)
/nRF52840 and LoRa/LORA_SPI_CS: IC2.19 (NSS), U5.11 (P0.12)
/nRF52840 and LoRa/SPI_MISO: IC2.16 (MISO), U5.14 (P0.14)
/nRF52840 and LoRa/SPI_MOSI: IC2.17 (MOSI), U5.13 (P0.13)
/nRF52840 and LoRa/SPI_SCK: IC2.18 (SCK), U5.18 (P0.19)
GND: C3.2, C8.2, C9.1, C10.2, C13.2, C14.2, C20.2, C21.2, C22.2, C23.2, C24.2, C25.1, C26.2, C27.1, C27.2, C28.2, C29.2, C31.2, D7.1 (K), IC2.1 (GND), IC2.2 (GND), IC2.3 (GND), IC2.4 (GND), IC2.5 (GND), IC2.6 (RXEN), IC2.7 (TXEN), IC2.10 (GND), IC2.11 (GND), IC2.12 (GND), IC2.20 (GND), IC2.22 (GND), L5.1, RST1.2, RST1.3, U5.32 (VSS_PA), U5.45 (VSS), U5.49 (VSS); also elsewhere on the board
I2C_SCL: U5.21 (P0.22); also elsewhere on the board
I2C_SDA: U5.22 (P0.23); also elsewhere on the board
unnamed: C30.2, L4.1, L5.2
unnamed: D7.2 (A), R16.2
unnamed: E1.1, L4.2
unnamed: L2.1, L3.2
unnamed: C31.1, L6.1, U5.31 (ANT)
unnamed: L2.2, U5.47 (DCC)
unnamed: C3.1, U5.1 (DEC1)
unnamed: C24.1, U5.34 (DEC3)
unnamed: C9.2, U5.35 (XC1), Y1.2
unnamed: C25.2, U5.36 (XC2), Y1.1
unnamed: R20.2, RST1.1, RST1.4, U5.16 (~RESET)
P0.04: U5.4 (P0.04); also elsewhere on the board
P0.05: U5.5 (P0.05); also elsewhere on the board
SWD_CLK: U5.27 (SWDCLK); also elsewhere on the board
SWD_IO: U5.26 (SWDIO); also elsewhere on the board
UART_RXD: U5.7 (P0.08); also elsewhere on the board
UART_TXD: U5.8 (P1.08); also elsewhere on the board

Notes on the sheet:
LoRa Module
Nordic SoC
RESET

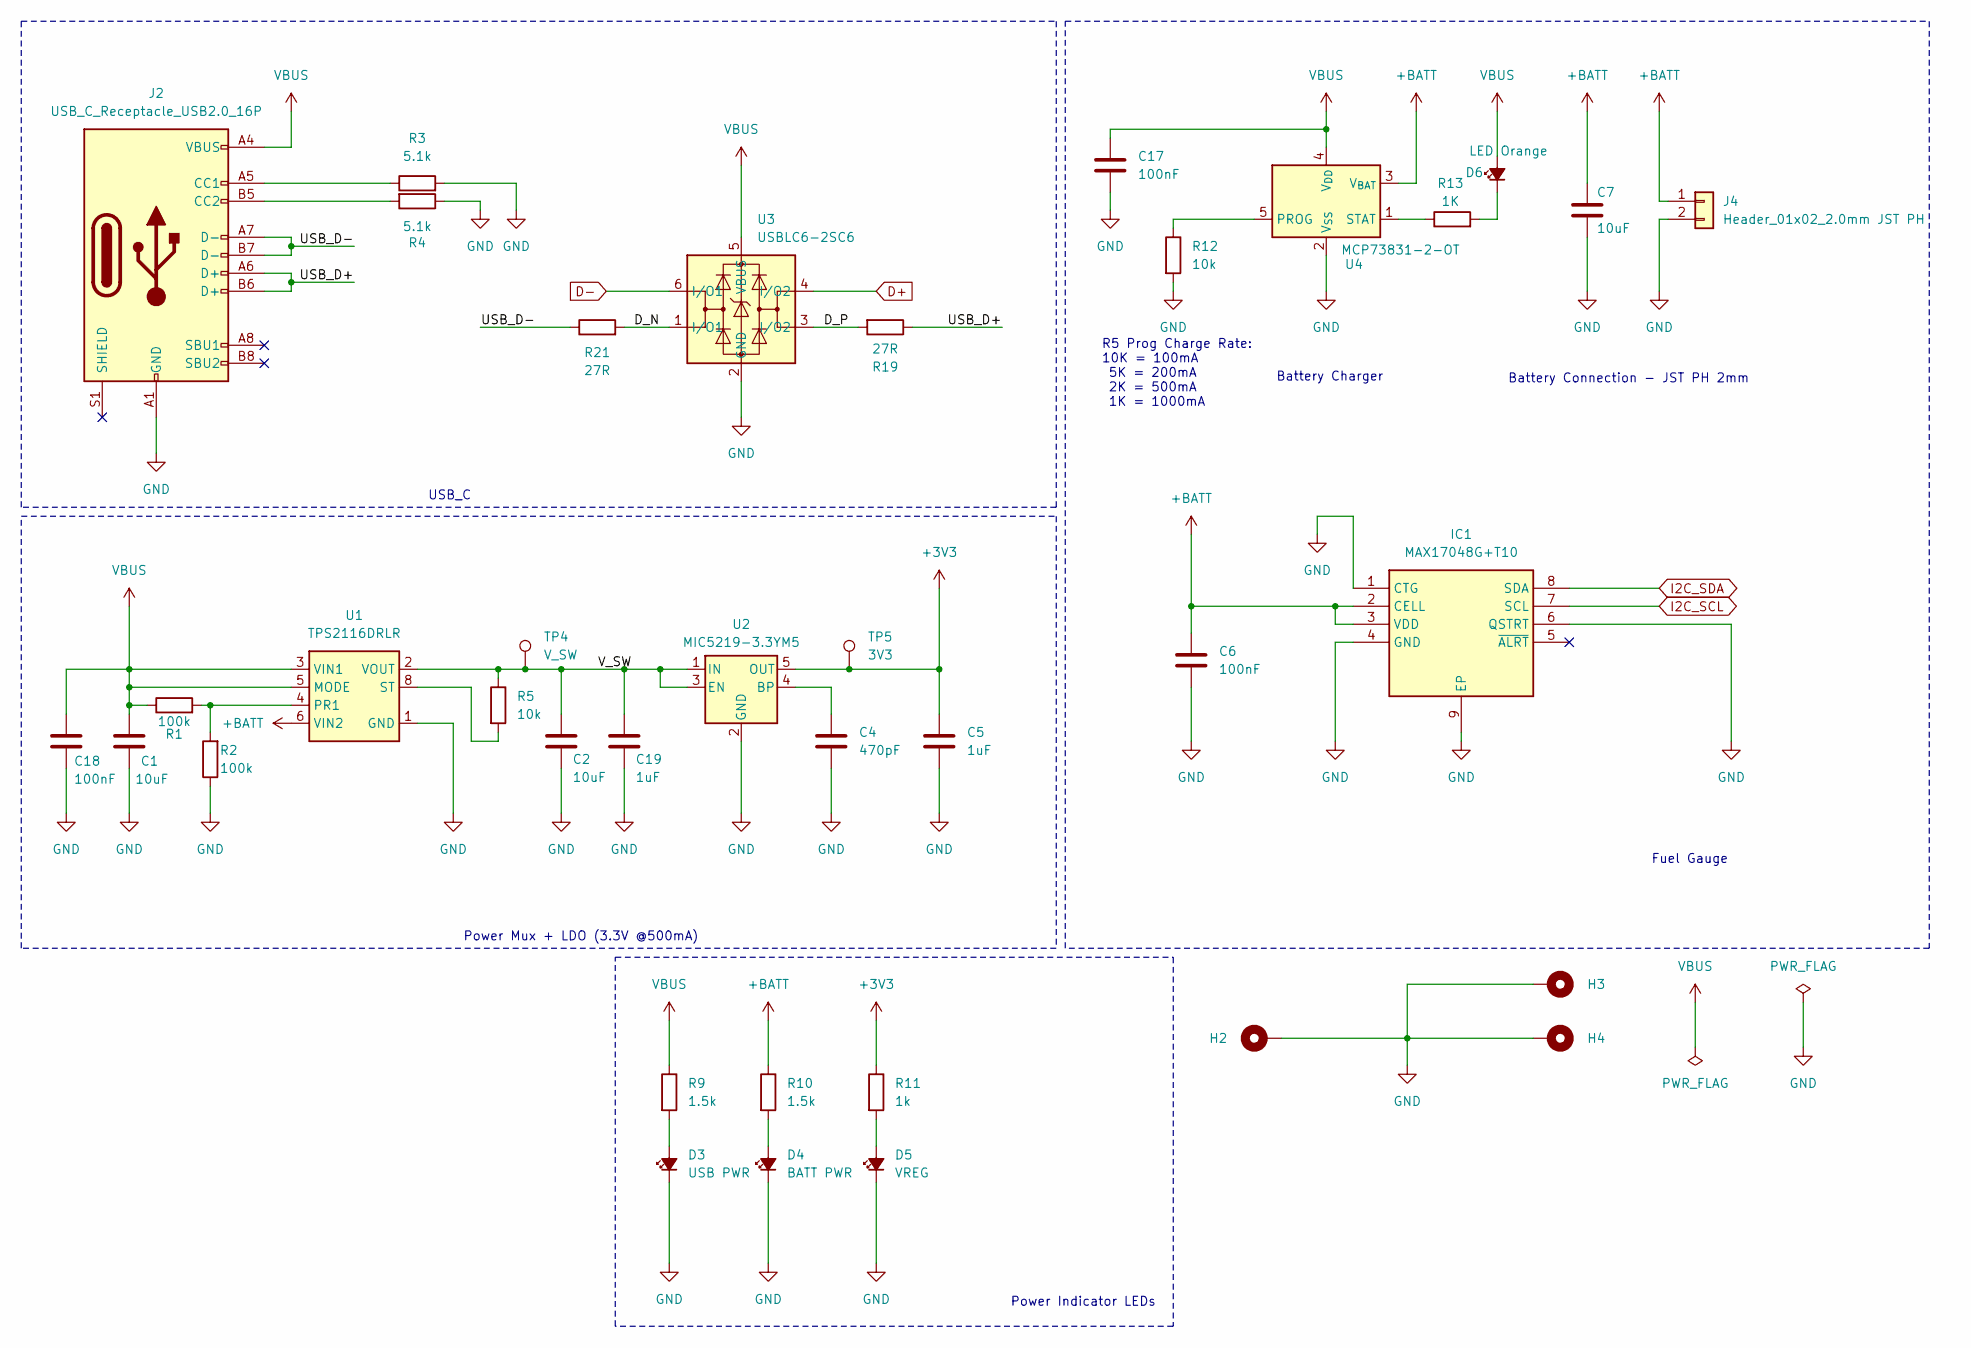
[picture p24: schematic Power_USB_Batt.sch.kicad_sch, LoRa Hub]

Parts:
C1, C2: 10uF; C_0603_1608Metric; MPN1 0603ZD106MAT4A; LCSC C19702
C4: 470pF; C_0805_2012Metric; MPN1 08051A471KAT2A
C5, C19: 1uF; C_0805_2012Metric; MPN1 08053C105KAT2A
C6, C17, C18: 100nF; C_0805_2012Metric; MPN1 08051C104KAT2A
C7: 10uF; C_1210_3225Metric; MPN1 C3225X7R1H106K250AC
D3: USB PWR; LED_0805; MPN1 APTD2012LSURCK
D4: BATT PWR; LED_0805; MPN1 APTD2012LSURCK
D5: VREG; LED_0805; MPN1 APTD2012LSURCK
D6: LED Orange; LED_0805; MPN1 APTD2012LCGCK
H2, H3, H4: MountingHole_Pad_M3; MountingHole_3.2mm_M3_DIN965_Pad_TopBottom
IC1: MAX17048G+T10; SON50P200X200X80-9N-D; Mouser Part Number 700-MAX17048G+T10
J2: USB_C_Receptacle_USB2.0_16P; USB_C_Receptacle_GCT_USB4110; MPN1 USB4110-GF-A
J4: Header_01x02_2.0mm JST PH; JST_S2B-PH-SM4-TB_LF__SN_; MPN1 S2B-PH-SM4-TB
R1, R2: 100k; R_0603_1608Metric; MPN1 ERJ-3EKF1003V
R3, R4: 5.1k; R_0805_2012Metric; MPN1 CRCW08055K10FKEA
R5: 10k; R_0805_2012Metric; MPN1 CRCW080510K0FKEA
R9, R10: 1.5k; R_0805_2012Metric; MPN1 CRCW08051K50FKEA
R11: 1k; R_0805_2012Metric; MPN1 CRCW08051K00FKEA
R12: 10k; R_0603_1608Metric; MPN1 ERJ-3EKF1002V
R13: 1K; R_0603_1608Metric; MPN1 ERJ-PA3F1001V
R19, R21: 27R; R_0603_1608Metric
TP4: V_SW; TestPoint_Pad_D1.0mm; MPN1 ---
TP5: 3V3; TestPoint_Pad_D1.0mm; MPN1 ---
U1: TPS2116DRLR; SOT-583-8; MPN1 TPS2116DRLR
U2: MIC5219-3.3YM5; SOT-23-5; MPN1 MIC5219-3.3YM5-TR
U3: USBLC6-2SC6; SOT-23-6; MPN1 USBLC6-2SC6
U4: MCP73831-2-OT; SOT-23-5; MPN1 MCP73831-2-OT

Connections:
+3V3: C5.1, R11.1, TP5.1, U2.5 (OUT); also elsewhere on the board
+BATT: C6.1, C7.1, IC1.2 (CELL), IC1.3 (VDD), J4.1, R10.1, U1.6 (VIN2), U4.3 (V_{BAT})
/Power/D_N: R21.2, U3.1 (I/O1)
/Power/D_P: R19.2, U3.3 (I/O2)
/Power/USB_D+: J2.A6 (D+), J2.B6 (D+), R19.1
/Power/USB_D-: J2.A7 (D-), J2.B7 (D-), R21.1
/Power/V_SW: C2.1, C19.1, R5.1, TP4.1, U1.2 (VOUT), U1.7 (VOUT), U2.1 (IN), U2.3 (EN)
D+: U3.4 (I/O2); also elsewhere on the board
D-: U3.6 (I/O1); also elsewhere on the board
GND: C1.2, C2.2, C4.2, C5.2, C6.2, C7.2, C17.2, C18.2, C19.2, D3.1 (K), D4.1 (K), D5.1 (K), H2.1, H3.1, H4.1, IC1.1 (CTG), IC1.4 (GND), IC1.6 (QSTRT), IC1.9 (EP), J2.A1 (GND), J2.A12 (GND), J2.B1 (GND), J2.B12 (GND), J4.2, R2.1, R3.2, R4.1, R12.2, U1.1 (GND), U2.2 (GND), U3.2 (GND), U4.2 (V_{SS}); also elsewhere on the board
I2C_SCL: IC1.7 (SCL); also elsewhere on the board
I2C_SDA: IC1.8 (SDA); also elsewhere on the board
unnamed: D3.2 (A), R9.2
unnamed: D4.2 (A), R10.2
unnamed: D5.2 (A), R11.2
unnamed: D6.1 (K), R13.2
unnamed: J2.A5 (CC1), R3.1
unnamed: J2.B5 (CC2), R4.2
unnamed: R1.2, R2.2, U1.4 (PR1)
unnamed: R5.2, U1.8 (ST)
unnamed: C4.1, U2.4 (BP)
unnamed: R12.1, U4.5 (PROG)
unnamed: R13.1, U4.1 (STAT)
VBUS: C1.1, C17.1, C18.1, D6.2 (A), J2.A4 (VBUS), J2.A9 (VBUS), J2.B4 (VBUS), J2.B9 (VBUS), R1.1, R9.1, U1.3 (VIN1), U1.5 (MODE), U3.5 (VBUS), U4.4 (V_{DD}); also elsewhere on the board

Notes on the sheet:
Battery Connection - JST PH 2mm
R5 Prog Charge Rate: 10K = 100mA 5K = 200mA 2K = 500mA 1K = 1000mA
Battery Charger
Power Indicator LEDs
Power Mux + LDO (3.3V @500mA)
USB_C
Fuel Gauge

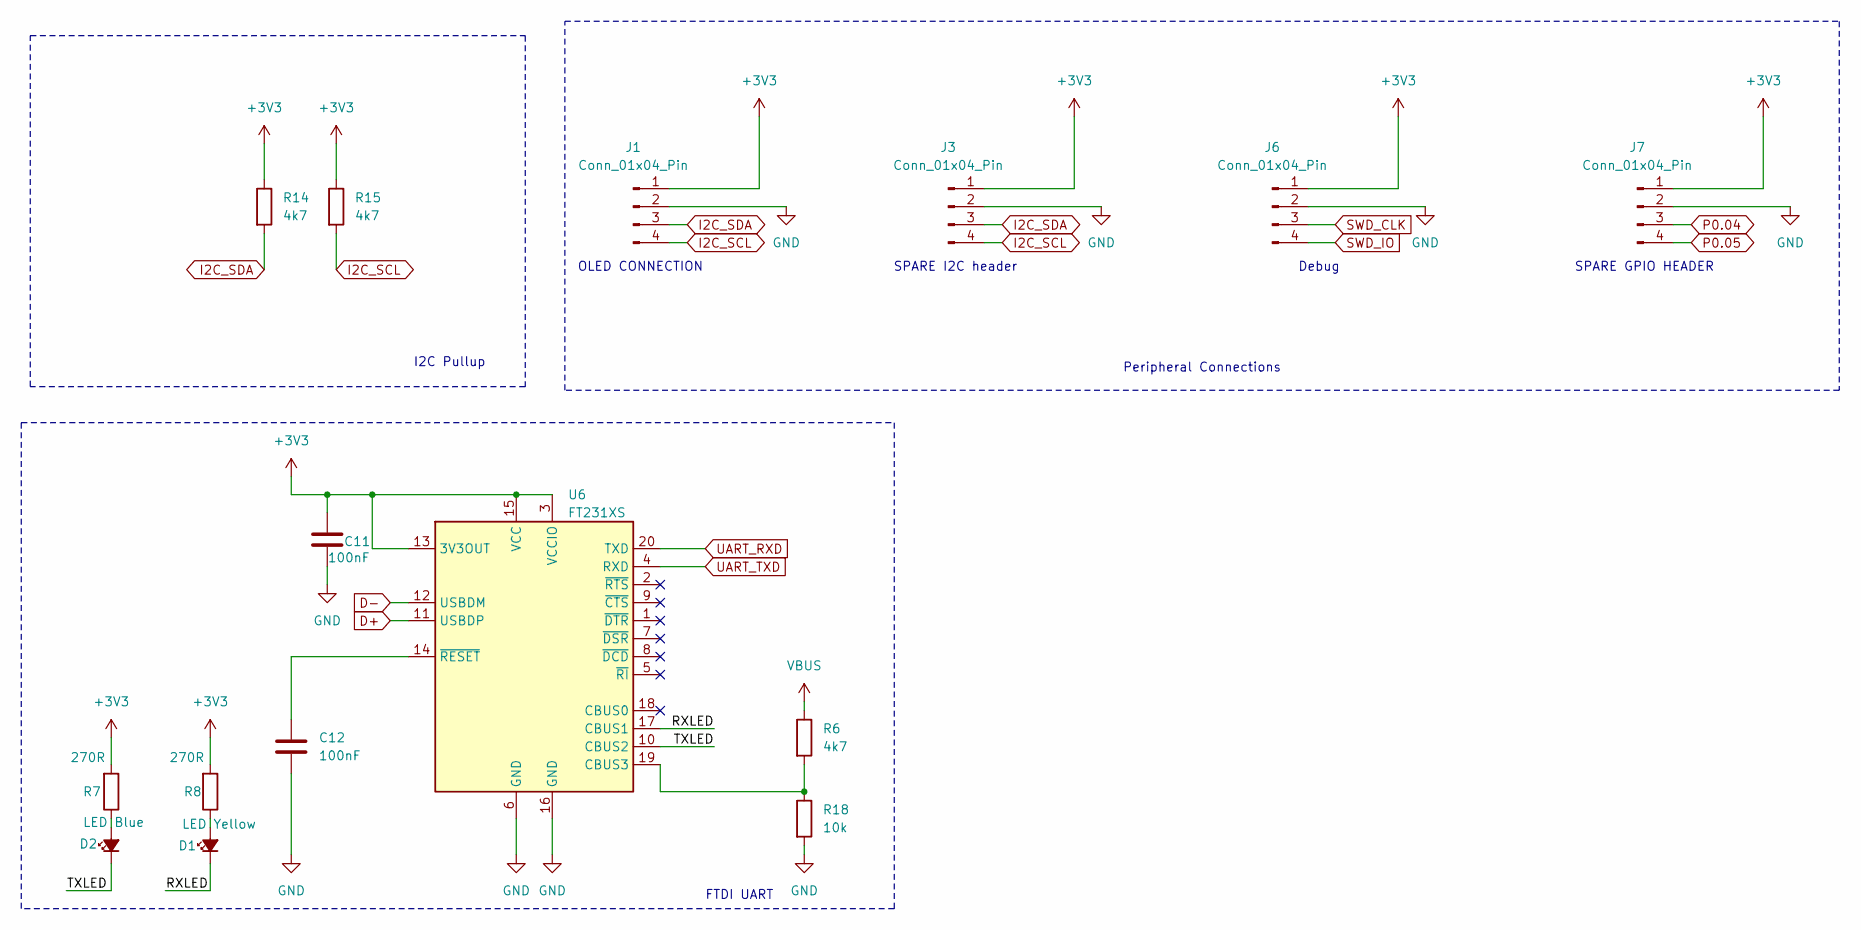
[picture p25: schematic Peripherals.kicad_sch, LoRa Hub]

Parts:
C11: 100nF; C_0603_1608Metric; MPN1 06033D104KAT2A
C12: 100nF; C_0603_1608Metric
D1: LED Yellow; LED_0805; MPN1 APTD2012LSYCK
D2: LED Blue; LED_0805; MPN1 APTD2012LQBC/D
J1, J3, J6, J7: Conn_01x04_Pin; PinHeader_1x04_P2.54mm_Vertical
R6: 4k7; R_0603_1608Metric
R7, R8: 270R; R_0603_1608Metric; MPN1 ERJ-UP3F2700V
R14, R15: 4k7; R_0402_1005Metric_Pad0.72x0.64mm_HandSolder; MPN1 560112110245
R18: 10k; R_0603_1608Metric; LCSC C25197
U6: FT231XS; SSOP-20_3.9x8.7mm_P0.635mm; MPN1 FT231XS

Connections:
+3V3: C11.2, J1.1, J3.1, J6.1, J7.1, R7.1, R8.1, R14.1, R15.1, U6.3 (VCCIO), U6.13 (3V3OUT), U6.15 (VCC); also elsewhere on the board
/Peripherals/RXLED: D1.1 (K), U6.17 (CBUS1)
/Peripherals/TXLED: D2.1 (K), U6.10 (CBUS2)
D+: U6.11 (USBDP); also elsewhere on the board
D-: U6.12 (USBDM); also elsewhere on the board
GND: C11.1, C12.2, J1.2, J3.2, J6.2, J7.2, R18.2, U6.6 (GND), U6.16 (GND); also elsewhere on the board
I2C_SCL: J1.4, J3.4, R15.2; also elsewhere on the board
I2C_SDA: J1.3, J3.3, R14.2; also elsewhere on the board
unnamed: D1.2 (A), R8.2
unnamed: D2.2 (A), R7.2
unnamed: R6.2, R18.1, U6.19 (CBUS3)
unnamed: C12.1, U6.14 (~RESET)
P0.04: J7.3; also elsewhere on the board
P0.05: J7.4; also elsewhere on the board
SWD_CLK: J6.3; also elsewhere on the board
SWD_IO: J6.4; also elsewhere on the board
UART_RXD: U6.20 (TXD); also elsewhere on the board
UART_TXD: U6.4 (RXD); also elsewhere on the board
VBUS: R6.1; also elsewhere on the board

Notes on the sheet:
Debug
FTDI UART
SPARE GPIO HEADER
I2C Pullup
OLED CONNECTION
Peripheral Connections
SPARE I2C header

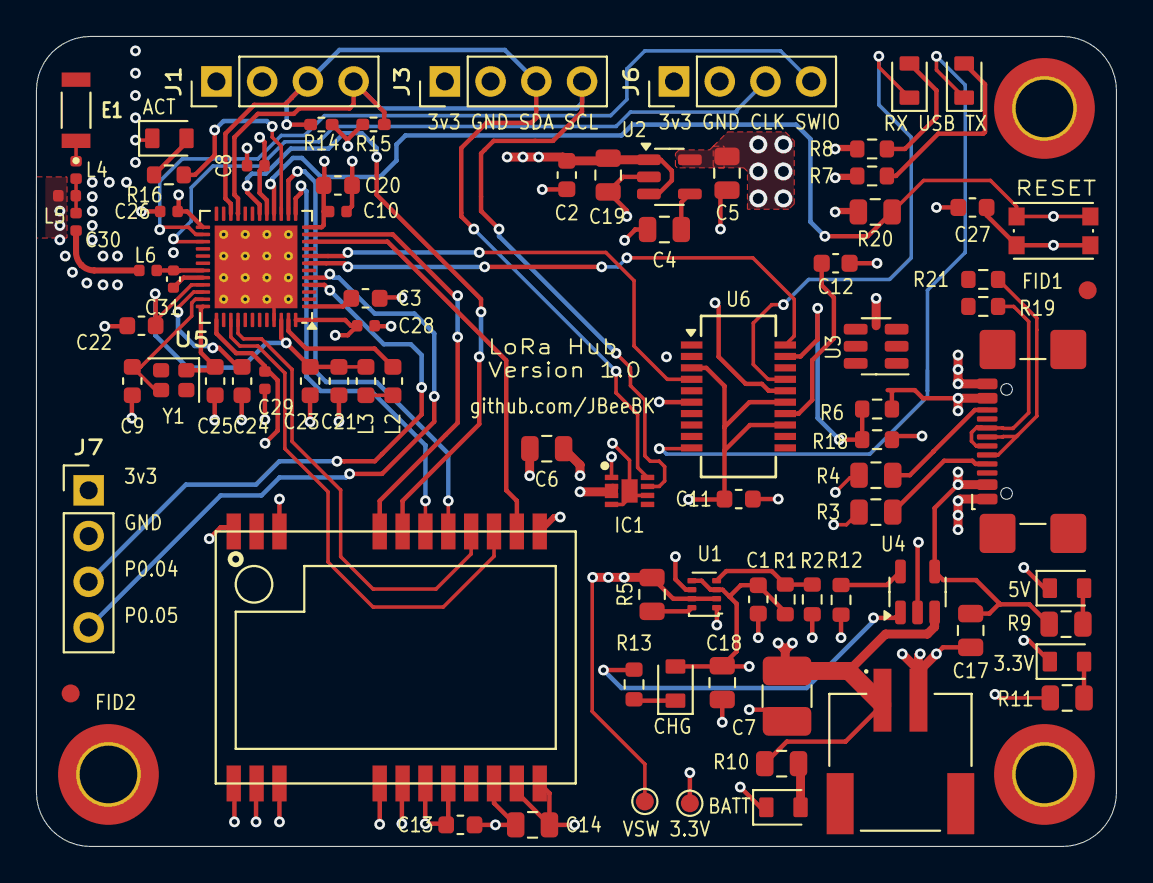
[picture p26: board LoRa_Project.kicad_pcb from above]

Board: 4 copper layers, 60.0 x 45.0 mm, 85 parts (0 on the bottom side), 57 nets.

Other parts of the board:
FID1, FID2: Fiducial_1mm_Mask2mm

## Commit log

2025-07-18 Added PDF Schematic to output assy
2025-07-18 updated FDTI cbus connections
    [LoRa_Project-B_Cu.gbr, LoRa_Project-B_Mask.gbr, LoRa_Project-B_Paste.gbr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]
2025-07-18 Rename folders to remove spaces for clean linking
    [2450AT18B100E.step, E22-900M22S.step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]
2025-07-21 Removed SMA for GPIO header placement.
    [LoRa_Project-B_Cu.gbr, LoRa_Project-B_Mask.gbr, LoRa_Project-B_Paste.gbr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]
2025-07-21 updated some library files/3d
    [KMR211NGLFS.STEP, LoRa_Project.kicad_pcb]
2025-07-23 Antenna output changed to fully isolate path
    [LoRa_Project-B_Cu.gbr, LoRa_Project-B_Mask.gbr, LoRa_Project-B_Paste.gbr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]
2025-07-24 updated silkscreen
    [LoRa_Project-B_Cu.gbr, LoRa_Project-B_Mask.gbr, LoRa_Project-B_Paste.gbr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]
2025-07-27 updated from generated script
    [LoRa_Project-B_Cu.gbr, LoRa_Project-B_Mask.gbr, LoRa_Project-B_Paste.gbr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]
2025-10-30 Added V1.0 assembly and testing notes, removed traces from ESD to move it V1.1
    [LoRa_Project.kicad_pcb, Power_USB_Batt.sch.kicad_sch]
